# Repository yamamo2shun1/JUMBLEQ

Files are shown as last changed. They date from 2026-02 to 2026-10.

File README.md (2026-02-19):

# JUMBLEQ
“JUMBLEQ” is short for “jumbled equipment”

## Audio Spec.
- Analog: 4in/4out
- USB: 4in/4out(USB Audio Class 2.0) and MIDI in/out
- Format: 24bit, 48kHz/96kHz

## Electronic Spec.
- MCU: [STM32H7S3Z8](https://www.st.com/en/microcontrollers-microprocessors/stm32h7s3z8.html)
- DSP: [ADAU1466](https://www.analog.com/jp/products/adau1466.html)
- CODEC: [AK4619](https://www.akm.com/jp/ja/products/audio/audio-codec/ak4619vn/)
- IO: [Gateron Low Profile Magnet Jade Pro](https://www.gateron.com/products/gateron-full-pom-low-profile-magnetic-jade-pro-switch-set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) x6 and Pot x8

## for Windows User
I’m developing JUMBLEQ as a solo project. I can’t realistically develop both an ASIO driver and the necessary firmware support on my own. If you’re using this device on Windows, please use [ASIO4ALL](https://asio4all.org/)—even if you’d prefer a dedicated ASIO driver.

## Firmware Update
JUMBLEQ uses a UF2 bootloader.
When you connect the USB cable while holding down SW3, it is recognized as a USB flash drive, so you can update the firmware simply by copying app.uf2—created using the procedure below—to the drive.
```
> arm-none-eabi-objcopy -O binary JUMBLEQ_Appli.elf app.bin
> python uf2conv.py -c -b 0x90010000 -f STM32H7RS -o app.uf2 app.bin
```

## Block Diagram
JUMBLEQ_diagram

## Pinout (main board rev.C)
JUMBLEQ_main_pinout_revC

## Modules
- Original  
[AK4619 Audio Module](https://github.com/YamamotoWorksDev/AK4619_Module)  
Magnetic Switch & POT Module

- Third party  
[0.96インチ 128×64ドット有機ELディスプレイ(OLED) 白色](https://akizukidenshi.com/catalog/g/g112031/)  
[SparkFun Qwiic OLED Display (0.91 in., 128x32)](https://www.sparkfun.com/sparkfun-qwiic-oled-display-0-91-in-128x32-lcd-24606.html)  
[SparkFun Qwiic EEPROM Breakout - 512Kbit](https://www.sparkfun.com/sparkfun-qwiic-eeprom-breakout-512kbit.html)

## Byte Options

XSPI1_HSLV
DTCM_AXI_SHARE

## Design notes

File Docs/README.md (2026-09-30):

# JUMBLEQ Documentation

This directory contains user guides, technical reference material, and development notes for JUMBLEQ.

## User Guide

- [Operation Guide](./user-guide/operation-guide.md) — controls, signal routing, and device operation
- [Firmware update](./user-guide/firmware-update.md) — update JUMBLEQ using the built-in UF2 bootloader
- [JUMBLEQ Configurator](./user-guide/configurator.md) — change device settings from the Web app or alternative Max versions
- [Notes for Windows users](./user-guide/windows.md) — low-latency audio driver options

## Technical Reference

- [Audio specifications](./reference/audio-spec.md)
- [Hardware](./reference/hardware.md) — main components and PCB modules
- [Signal flow](./reference/signal-flow.md) — hardware block diagram and audio routing
- [MIDI](./reference/midi/README.md) — receive and transmit specifications
- [Naming conventions](./reference/naming-conventions.md) — self-written Core code identifiers

## Development

- [Development environment](./development/environment.md)
- [ST-LINK debug configuration](../STM32CubeIDE/docs/Debug_Configuration-STLINK.md)
- [J-Link debug configuration](../STM32CubeIDE/docs/Debug_Configuration-JLINK.md)
- [Build and UF2 generation](./development/build-and-uf2.md)
- [STM32H7S3 errata](./development/errata.md)
- [STM32CubeIDE project overview](../STM32CubeIDE/README.md)

## Project History

See the [Gallery](../Gallery/) for photographs and notes from each prototype stage.

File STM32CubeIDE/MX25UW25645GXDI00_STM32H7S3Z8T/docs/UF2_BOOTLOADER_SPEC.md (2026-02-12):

# UF2ブートローダ 仕様整理（MX25UW25645GXDI00_STM32H7S3Z8T）

更新日: 2026-02-12

## 前提
- 対象プロジェクト: MX25UW25645GXDI00_STM32H7S3Z8T
- 現状は外部フラッシュ（XIP）アプリを起動するシンプル構成
- 追加するのは UF2 ブートローダ（USB MSC 経由）

## 決定済み要件
- ブートモード入口: SW2 を押しながら電源 ON（USB 接続）
- USB: HS（High Speed）使用
- 検証: CRC32 のみ
- アプリ配置: 外部フラッシュ上の固定オフセット
- ボリューム名: UF2BOOT
- USB VID/PID: 0x31BF / 0x0100

## 目的
- USB MSC として UF2 を受け取り、外部フラッシュのアプリ領域へ書き込み
- CRC32 検証後に XIP でアプリ起動

## 起動フロー（方針）
1. 低レベル初期化（クロック / MPU / キャッシュ）
2. XSPI + ExtMem Manager 初期化
3. ブートモード判定
   - SW2 押下かつ USB 接続なら UF2 モード
   - それ以外はアプリ起動
4. UF2 モード
   - USB MSC デバイス起動
   - UF2 ブロック受信 -> 外部フラッシュ書き込み
   - CRC32 検証 OK ならメタデータ更新
5. 通常モード
   - XIP アプリへジャンプ

## メモリマップ（方針）
- 内蔵フラッシュ
  - ブートローダ格納
- 外部フラッシュ（32MB = 0x0200_0000）
  - META 領域: 0x9000_0000 - 0x9000_FFFF (64KB)
  - APP 領域: 0x9001_0000 - 0x9040_FFFF (4MB)
  - 予備:     0x9041_0000 - 0x91FF_FFFF (残り)

### 固定オフセット
- `APP_OFFSET = 0x0001_0000` (64KB)
- `APP_BASE   = 0x9000_0000 + APP_OFFSET = 0x9001_0000`
- `EXTMEM_XIP_IMAGE_OFFSET` は `APP_OFFSET` と同値にする
- `EXTMEM_HEADER_OFFSET` は 0

※ META 領域は最小 4KB でも良いが、消去セクタ境界に合わせ 64KB を確保する前提。

## 消去・書き込み戦略（推奨）
- デバイスは 4KB セクタ消去と 64KB ブロック消去をサポート
- APP 領域は 64KB ブロック単位で消去（更新時間短縮のため）
- META のような小領域は 4KB セクタ消去を許可
- UF2 受信時は、書き込み対象アドレス範囲に対応する 64KB ブロックのみ事前消去

## UF2 処理方針
- USB MSC で 512B UF2 ブロックを受信
- `targetAddr` を外部フラッシュ APP 領域にマップ
- ブロック毎に書き込み
- 受信完了後、CRC32 を算出
- CRC32 OK -> META 更新

## UF2 MSC 仮想ディスク構成（提案）
- 目的: 4MB アプリの UF2 ファイル（サイズ約 8MB）を無理なく転送できる容量を確保
- ディスクサイズ: 16MB（16384KB）
- セクタサイズ: 512B
- クラスタサイズ: 1 セクタ
- FAT: FAT16
- ルートエントリ数: 64
- ボリュームラベル: `UF2BOOT`

### 生成するファイル（読み取り専用）
- `INFO_UF2.TXT`
  - ボード名/ビルド情報/対応範囲など
- `INDEX.HTM`
  - 製品ページや手順案内への誘導（必要なら）
- `CURRENT.UF2`（任意）
  - 現在のアプリを吸い出す用途（不要なら省略）

### 書き込み受理ルール
- UF2 ブロックのみ受理（UF2 マジック一致）
- `targetAddr` が `APP_BASE .. APP_BASE + APP_SIZE - 1` にあるものだけ書き込み
- 範囲外は無視（ディスクの通常書き込みは無視）
- 初回書き込み時に対象 64KB ブロックだけ消去
- `numBlocks` と `blockNo` を用いて受信完了を判断し CRC32 検証

## 運用手順（UF2 生成と書き込み）
### 前提
- アプリのリンクアドレスは `0x90010000`（APP_BASE）
- UF2 変換は `uf2conv.py` を使用
- `uf2families.json` は `uf2conv.py` と同じフォルダに置く
- family ID: `STM32H7RS = 0x6db66083`

### 1. ELF -> BIN 変換
```
arm-none-eabi-objcopy -O binary app.elf app.bin
```

### 2. BIN -> UF2 変換
```
python uf2conv.py -c -b 0x90010000 -f STM32H7RS -o app.uf2 app.bin
```

### 3. 書き込み
- SW2 押下で電源 ON（USB 接続）
- PC に `UF2BOOT` がマウントされる
- `app.uf2` を `UF2BOOT` にドラッグ＆ドロップ
- 書き込み完了後、自動でアプリへジャンプ

## CRC32 メタデータ仕様（提案）

### 位置
- META ベース: `0x9000_0000`
- 先頭 256B をメタデータ領域として使用

### 形式（リトルエンディアン）
```
typedef struct {
  uint32_t magic;       // 0x4D544131 ('MTA1')
  uint16_t version;     // 0x0001
  uint16_t header_size; // sizeof(MetaHeader) = 64
  uint32_t flags;       // bit0: valid
  uint32_t app_base;    // 0x90010000
  uint32_t app_size;    // max 0x00400000
  uint32_t app_crc32;   // CRC32(アプリ全体)
  uint32_t build_id;    // 任意 (ビルド番号 or Git short hash)
  uint32_t image_size;  // 実際に書き込んだサイズ
  uint32_t reserved[6]; // 0
} MetaHeader;
```

### 更新タイミング
- UF2 受信完了後に CRC32 を算出
- CRC32 が一致した場合のみ `flags.valid = 1` として META を更新
- 更新時は 4KB セクタ消去 -> 先頭 256B 書き込み

### 検証タイミング
- 起動時に `magic/version/header_size` を確認
- `flags.valid == 1` かつ `app_size` が上限内なら CRC32 検証
- 一致すれば XIP 起動、失敗なら UF2 モードへ

## LED 表示パターン（提案）
- 通常起動（XIPアプリへジャンプ）: LED0 1秒点灯 -> 消灯
- UF2待機（SW2押下で起動した更新モード）: LED0 ゆっくり点滅（1Hz）
- UF2書き込み中: LED1 速い点滅（4Hz）
- CRC32検証中: LED2 ブリージング（0.5Hz）
- 検証OK / 起動準備: LED0+LED1+LED2 を200ms同時点灯 -> 消灯
- 検証NG / エラー: LED2 2連点滅（100ms×2）を1秒周期で繰り返し
- USB未接続でSW2押下（無効）: LED1 3回短点滅

## XIP 起動方針
- `VTOR = APP_BASE`
- `MSP = *(uint32_t*)APP_BASE`
- `PC  = *(uint32_t*)(APP_BASE + 4)`
- キャッシュ clean/invalidate を実施してからジャンプ

## 現行 Boot 実装の確認（2026-02-12）
- `BOOT_Application()` は `stm32_boot_xip.c` に実装
- `MapMemory()` で `extmem_list_config` の全メモリを `EXTMEM_MemoryMappedMode()` へ
- `EXTMEM_MEMORY_BOOTXIP` が非対応なら `BOOT_ERROR_INCOMPATIBLEMEMORY`
- `JumpToApplication()` は以下の順で実行
  - `EXTMEM_GetMapAddress(EXTMEM_MEMORY_BOOTXIP, &Application_vector)`
  - `EXTMEM_XIP_IMAGE_OFFSET` と `EXTMEM_HEADER_OFFSET` を加算（現状は未定義のため両方 0）
  - SysTick / I-Cache / D-Cache を停止
  - `VTOR` 設定 -> `MSP` 設定 -> `PC` にジャンプ
- `Boot/Core/Src/main.c` では以下の順に初期化
  - `MX_XSPI1_Init()`
  - `MX_EXTMEM_MANAGER_Init()`
  - `BOOT_Application()`
- MPU では `0x90000000` を 32MB サイズで実行可・キャッシュ可として設定
- リンカは内蔵フラッシュ `0x08000000` から 64KB をブートローダ領域として使用
- `extmem_list_config` は NOR SFDP + XSPI1 + 8lines で初期化

## 次のアクション候補（残り）
1. 実装作業（ブートモード判定、USB MSC、UF2書き込み、META更新、LED制御）に着手

## 実装状況（2026-02-12）
- ブートモード判定、UF2解析、外部フラッシュ書き込み、META更新、LED制御の骨格を実装
- USB MSC は TinyUSB で動作（HS）
- MSC は最小FAT16（16MB）を返す読み取り専用ディスクとして実装
- UF2 書き込み後に CRC32 検証 -> 自動ジャンプまで動作確認済み

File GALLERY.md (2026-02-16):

## Gallery
DSCF6374
DSCF6384
DSCF6378

## Prototype 2
DSCF6407
DSCF6405
DSCF6411
DSCF6414
DSCF6415
DSCF6416

## Prototype 1
DSCF6165-2
DSCF6172-2
DSCF6176-2

## Main board
OTO_overall
OTO_top

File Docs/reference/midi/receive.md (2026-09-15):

# MIDI Receive Specification

This document describes the MIDI receive specification based on the `JUMBLEQ/Appli/Core` implementation as of September 2026.

## 1. Overview

- Incoming MIDI messages are processed over USB MIDI.
- Incoming messages used to change UI settings are accepted only on **MIDI Ch. 15** (1-based channel numbering).

## 2. Program Change (Host -> Device)

### 2.1 Acceptance Conditions

- Program Change messages are accepted only on MIDI Ch. 15.
- Program Change messages on all other channels are ignored.

### 2.2 Program Change Map

| PC Number | Function |
|---:|---|
| 0/1 | Set the Ch. 1 input type (Line / Phono). |
| 2/3 | Set the Ch. 2 input type (Line / Phono). |
| 4/5/6/7 | Assign an input source (Ch. 1 / Ch. 2 / USB[1/2] / USB[3/4]) to Channel Fader A. |
| 8/9/10/11 | Assign an input source (Ch. 1 / Ch. 2 / USB[1/2] / USB[3/4]) to Channel Fader B. |
| 12/13/14/15 | Assign an input source (Ch. 1 / Ch. 2 / USB[1/2] / USB[3/4]) to Post Fader. |
| 16/17/18 | Set the Ch. 1 input mode (Off / DVS / SYNTH). |
| 19/20/21 | Set the Ch. 2 input mode (Off / DVS / SYNTH). |
| 22/23/24 | Select the Return source (USB[1/2] / USB[3/4] / None). |
| 25/26/27/28 | Select the headphone output source (FADER_A / FADER_B / THRU / MASTER). |
| 29/30 | Assign magnetic switch 2 to the auxiliary fade-down function for Channel Fader A or B. |
| 31/32 | Assign magnetic switch 3 to the auxiliary fade-down function for Channel Fader A or B. |
| 33/34 | Set the Channel Fader A direction (Normal / Reverse). |
| 35/36 | Set the Channel Fader B direction (Normal / Reverse). |
| 37/38/39 | Select the global SYNTH Ratio Set (Octave / Harmonic / Chord). |
| 40/41/42/43 | Select the global SYNTH Warp Algorithm (Clean / Crossfold / Ring Mod / Comparator). |
| 120/121 | Disable or enable Channel Fader curve edit mode. |
| 122/123 | Select the output mode (CC / Note) for magnetic controls and channel fader sensors. |
| 124 | Arm the 10-second physical confirmation window for UF2 bootloader mode. |
| 125 | Cancel the UF2 bootloader confirmation window. |
| 126 | Transmit a dump of the parameters currently configured on the device. |
| 127 | Save the current settings to EEPROM. |

Notes:

- `PC24` selects `None`, which disables the Return signal path.
- Auxiliary fade-down assignments for magnetic switches 2 and 3 take effect immediately when the Program Change message is received.
- The default assignments are Channel Fader A for magnetic switch 2 and Channel Fader B for magnetic switch 3.
- Direction can be configured independently for Channel Faders A and B and takes effect immediately. The default is Normal for both faders.
- Reverse inverts the final fader response for Fade Up and all Fade Down controls assigned to that fader, including auxiliary Fade Down controls. It does not change the live MIDI values transmitted by the individual magnetic sensors.
- Ratio Set and Warp Algorithm are shared by Input Ch. 1 and Input Ch. 2. Changes take effect immediately for both oscillator instances.
- Warp Amount is controlled independently by the existing CC.5 potentiometer. Selecting Clean bypasses warping, so CC.5 has no audible effect until another Warp Algorithm is selected.
- `PC127` saves the complete device configuration listed in Section 6 to EEPROM, including the SYNTH Ratio Set and Warp Algorithm.
- `PC126` transmits the **current operating state (parameters eligible for saving)** rather than reading and transmitting the EEPROM contents.
- `PC124` never resets the device by itself. After it is received, SW3 must be observed released and then held continuously for 2 seconds before the device resets into UF2 mode.
- The PC124 confirmation window is cancelled by `PC125`, a 10-second timeout, or USB disconnection. Repeated PC124 messages do not extend an active window.
- PC124 and PC125 are transient commands and are not included in configuration dumps or EEPROM storage.

## 3. Safe UF2 Bootloader Transition

The Configurator can request a safe transition to the UF2 bootloader as follows:

1. Send PC124 on Ch. 15.
2. Wait for the main OLED to request physical confirmation.
3. Release SW3, then hold it continuously for 2 seconds.
4. Keep SW3 held while the device resets and the UF2 mass-storage volume appears.

The main OLED shows the remaining time, the required switch action, and cancellation or timeout status. PC124 received while a confirmation window is already active is ignored and does not restart or extend the timer.

After the 2-second hold is accepted, the firmware clears both OLED displays and then resets while SW3 remains pressed. The existing bootloader selects UF2 mode using its normal startup switch check; no persistent boot request is stored.

## 4. Control Change (Host -> Device)

### 4.1 Acceptance Conditions

Control Change messages are accepted only when all of the following conditions are met:

- Channel Fader curve edit mode is enabled.
- The MIDI channel is Ch. 15.
- The CC number is supported (`20`, `21`, or `22`).

### 4.2 Control Change Map

| CC Number | Parameter | CC Value |
|---:|---|---|
| 20 | `XFADE_CURVE_A` | 0 to 127 |
| 21 | `XFADE_CURVE_B` | 0 to 127 |
| 22 | `DVS_FADER_DELAY_MS` | 0 to 120 ms; values 121 to 127 are clamped to 120 ms |

Curve response:

- `0` selects the strongest late-rise curve; the level changes mainly near the end of the key travel.
- `64` selects an exactly linear response across the full key travel.
- `127` selects the strongest early-rise curve; the level changes sharply near the start of the key travel.
- The late- and early-rise families use point-reflected exponential curves.
- The default value is `64` for both Channel Faders A and B.
- The DVS fader delay defaults to 50 ms and is shared by both input channels.

## 5. `curve_edit_mode` (Channel Fader Curve Edit Mode) Behavior

- Use Program Change messages to enable or disable the mode (`PC121` ON / `PC120` OFF).
- While enabled, the main OLED shows the current curve CC values for Channel Faders A and B together with a graphical preview of each curve. The first line shows `FADER DLY: nms` when either DVS channel is enabled and `FADER DLY: ---` when both are disabled.
- While disabled, the main OLED uses its normal display and shows the gain values for each input and output channel.
- There is no automatic timeout.

## 6. EEPROM Storage and Startup Restore

- Save trigger: `PC127` on Ch. 15
- Saved parameters:
  - CH1/CH2 input types
  - Channel Fader A/B and Post Fader assignments
  - CH1/CH2 input modes (Off / DVS / SYNTH)
  - DVS magnetic-switch fader delay
  - Return source assignment
  - Headphone output source
  - Magnetic output mode (CC / Note)
  - Auxiliary fade-down assignments for magnetic switches 2 and 3
  - Direction settings (Normal / Reverse) for Channel Faders A/B
  - Curve settings for Channel Faders A/B
  - SYNTH Ratio Set and Warp Algorithm shared by both input channels
- EEPROM record version: `0x0009`
  - `0x0008` records are migrated with Ratio Set = Octave and Warp Algorithm = Crossfold.
  - `0x0007` records are loaded with a 50 ms DVS fader delay, their DVS booleans are converted to Off/DVS input modes, and the same SYNTH defaults are applied.

## 7. Implementation Notes

- Channel values in the implementation are zero-based (for example, `14` = MIDI Ch. 15).
- The Ch. 15 restrictions for incoming Program Change and Control Change messages are checked in their respective dispatch functions.
- Internally, `CC64` maps to zero exponential curvature. Values below it produce negative (late-rise) curvature, and values above it produce positive (early-rise) curvature. The absolute bipolar curve amount is cubed before it scales the exponent, providing finer adjustment around the linear midpoint while preserving the endpoint curves. The maximum curvature is calibrated so the `CC127` response reaches 90% output at 2% key travel. EEPROM retains the legacy normalized-width representation for backward compatibility; that stored value is converted back to its CC value before the exponential curve is evaluated.

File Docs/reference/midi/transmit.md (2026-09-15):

# MIDI Transmit Specification

This document describes the MIDI transmit specification based on the `JUMBLEQ/Appli/Core` implementation as of September 2026.

## 1. Overview

- Outgoing MIDI messages are sent to the host over USB MIDI.
- Live control output is sent on MIDI Ch. 1.
- Configuration dump responses are sent on MIDI Ch. 15.

## 2. Live Control Output (Device -> Host)

The device transmits the following messages on MIDI Ch. 1. In the implementation, channel value `0` corresponds to MIDI Ch. 1.

| Control | CC Mode | Note Mode | Description |
|---|---|---|---|
| MIDI-assigned potentiometers | CC `0..4` | — | Sends the current knob value. |
| Magnetic controls 0..3 | CC `12..15` | Notes `68..71` | Output mode is selected using `PC122` or `PC123`. |
| Magnetic channel fader sensors 0..5 | CC `20..25` | Notes `60..65` | Output mode is selected using `PC122` or `PC123`. |

In CC mode, magnetic channel fader updates are sent only when the normalized raw value changes by more than `0.01`. This reduces MIDI traffic and jitter.

In Note mode, magnetic controls and channel fader sensors send Note On/Off messages. The peak sensor value measured during the initial 12 ms window is converted to Note On velocity.

CC20 through CC22 have different roles depending on the MIDI channel: on Ch. 1 they carry live values from magnetic channel fader sensors 0 through 2. In a Ch. 15 configuration dump, CC20 and CC21 carry curve settings for Channel Faders A and B, while CC22 carries the DVS fader delay.

## 3. Implementation Notes

- Channel values in the implementation are zero-based (for example, `0` = MIDI Ch. 1).
- `PC122` selects CC output for magnetic controls and channel fader sensors.
- `PC123` selects Note output for magnetic controls and channel fader sensors.

## 4. Configuration Dump Response (When PC126 Is Received)

When the device receives `PC126` on Ch. 15 from the host, it sends the current values of all parameters eligible for saving back to the host.

- Transmit channel: **MIDI Ch. 15** (implementation value `14`)
- Message types: Program Change and Control Change

### 4.1 Program Change (Device -> Host, Ch. 15)

| PC Value | Meaning |
|---:|---|
| 0/1 | Ch. 1 input type (Line / Phono) |
| 2/3 | Ch. 2 input type (Line / Phono) |
| 4/5/6/7 | Channel Fader A source (Ch. 1 / Ch. 2 / USB[1/2] / USB[3/4]) |
| 8/9/10/11 | Channel Fader B source (Ch. 1 / Ch. 2 / USB[1/2] / USB[3/4]) |
| 12/13/14/15 | Post Fader source (Ch. 1 / Ch. 2 / USB[1/2] / USB[3/4]) |
| 16/17/18 | Ch. 1 input mode (Off / DVS / SYNTH) |
| 19/20/21 | Ch. 2 input mode (Off / DVS / SYNTH) |
| 22/23/24 | Return source (USB[1/2] / USB[3/4] / None) |
| 25/26/27/28 | Headphone output source (FADER_A / FADER_B / THRU / MASTER) |
| 29/30 | Auxiliary fade-down assignment for magnetic switch 2 (Channel Fader A/B) |
| 31/32 | Auxiliary fade-down assignment for magnetic switch 3 (Channel Fader A/B) |
| 33/34 | Channel Fader A direction (Normal / Reverse) |
| 35/36 | Channel Fader B direction (Normal / Reverse) |
| 37/38/39 | Global SYNTH Ratio Set (Octave / Harmonic / Chord) |
| 40/41/42/43 | Global SYNTH Warp Algorithm (Clean / Crossfold / Ring Mod / Comparator) |
| 122/123 | Output mode for magnetic controls and channel fader sensors (CC / Note) |

The dump contains exactly one value for each setting group, including one Ratio Set value and one Warp Algorithm value. Ratio Set and Warp Algorithm are global settings shared by both SYNTH channels.

### 4.2 Control Change (Device -> Host, Ch. 15)

| CC Number | Meaning |
|---:|---|
| 20 | `XFADE_CURVE_A` (`0` = strongest late rise, `64` = linear, `127` = strongest early rise) |
| 21 | `XFADE_CURVE_B` (`0` = strongest late rise, `64` = linear, `127` = strongest early rise) |
| 22 | `DVS_FADER_DELAY_MS` (`0..120` ms) |

The curve values use the same scale as incoming curve-edit Control Change messages. The DVS fader delay value is transmitted directly in milliseconds. This allows the host to restore the current settings without conversion.

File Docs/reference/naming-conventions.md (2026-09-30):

# JUMBLEQ 自作コード命名規則

この文書は `STM32CubeIDE/JUMBLEQ/Appli/Core` の自作コードに適用する命名規則を定義する。
外部・生成コードの識別子には適用しない。

## 対象外

- STM32CubeMX生成コードの識別子（`MX_*`、`HAL_*`、`Start*Task`、`*TaskHandle`、`main.c` の生成部など）
- HAL / CMSIS / FreeRTOS / TinyUSB / SEGGER / SigmaStudio+ / TCPP0203 / stm32-ssd1306 が所有する識別子
- DMA/リンカ契約シンボル（`adc_val`、`sai_tx_dma_buf`、`sai_rx_dma_buf`、`Node_*`、`List_*`）
- FreeRTOS契約シンボル（`ucHeap`）

## 関数

- 公開API: `<module>_<verb>_<object>` の lower_snake_case。
- private（static）関数: lower_snake_case。所有モジュールの接頭辞を付けることを推奨する。
- 識別子内で大文字小文字を混ぜない（`typeA` ではなく `type_a`）。

## 型

型名は `<component>_<name>_t` の lower_snake_caseとし、匿名 struct / union / enum の typedef で定義する。
componentは次の優先順で決める。

1. 永続診断型は、対応する診断グローバル名から `g_` を除いた名前をcomponentとする。
   - 例: `g_audio_tx_diagnostics` → `audio_tx_diagnostics_t`
   - 例: `g_audio_usb_feature_diagnostics` → `audio_usb_feature_diagnostics_t`
   - 例: `g_sigma_spi_diagnostics` → `sigma_spi_diagnostics_t`
2. それ以外は所有モジュールの接頭辞をcomponentとする。

| 所有モジュール（定義ファイル） | component |
| --- | --- |
| adau1466.h / adau1466.c | `adau1466_` |
| eeprom.h / eeprom.c | `eeprom_` |
| eeprom_config_internal.h / eeprom_config.c | `eeprom_config_` |
| timecode_oscillator.h / timecode_oscillator.c | `timecode_oscillator_` |
| timecode_synth.h / timecode_synth.c | `timecode_synth_` |
| audio_control_internal.h / audio_control.c | `audio_control_` |
| audio_transport_internal.h / audio_transport.c | `audio_transport_` |
| audio_usb_control_internal.h / audio_usb_control.c | `audio_usb_control_` |
| ui_control.h / ui_control.c | `ui_control_` |
| ui_persist_internal.h | `ui_persist_` |
| ui_midi_control_internal.h / ui_midi_control.c | `ui_midi_control_` |
| ui_uf2_control_internal.h / ui_uf2_control.c | `ui_uf2_control_` |
| ui_pot_control_internal.h / ui_pot_control.c | `ui_pot_control_` |
| ui_routing_control_internal.h / ui_routing_control.c | `ui_routing_`（関数接頭辞が `ui_routing_*` のため） |
| ui_ch_fader_internal.h / ui_ch_fader.c | `ui_ch_fader_` |
| led_control.c | `led_` |

- 所有が定義ファイルと異なる型は所有をコメント等で明記する。
  例: `audio_transport_failure_t` は audio_transport 所有（include循環を避けるため宣言のみ `audio_diagnostics_internal.h` に置く）。

## 変数・定数

- ファイルスコープオブジェクト: `static` + `s_` + lower_snake_case。const有無を問わない。
- 複数翻訳単位で共有するグローバル: `g_` + lower_snake_case。型名と一致させる必要はない。
- ブロックスコープstatic: 宣言位置で局所性が明確なため `s_` は付けず、lower_snake_caseとする。
- マクロ・enum値: UPPER_SNAKE_CASE。

## 単位

物理量を表す名前に単位接尾辞を付ける。無次元（0..1の比率など）には付けない。

`_ms`、`_us`、`_hz`、`_db`、`_bytes`、`_words`、`_frames`、`_samples`、`_count`、`_tick`

## 略語

次の略語を許容する。

`src`、`db`、`cfg`、`ptr`、`buf`、`len`、`idx`、`num`、`min`、`max`、`avg`、`prev`、`init`

- 同一概念で長短を混在させない（例: `audio_diag_` と `audio_diagnostics_` を混ぜない）。
- モジュールAPIの接頭辞は、そのモジュールの公開・内部ヘッダーの関数接頭辞と一致させる。

## 診断変数の例外

デバッガから参照する診断変数は、次の例外を認める。

- `dbg_` + lower_snake_case（例: `dbg_tx_used_min`、`dbg_usb_isr_count`）
- `.noinit` に置くFault記録（`g_hardFaultInfo` / `HardFaultInfo_t`）は名称・可視性とも変更しない。

診断変数の可視性（static / 非static）を変更する場合は、デバッガのWatch式や手動デバッグでの用途を確認し、
参照名の変更を明示してから行う。

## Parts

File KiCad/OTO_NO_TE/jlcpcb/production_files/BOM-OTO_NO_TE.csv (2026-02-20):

Comment | Designator | Footprint | LCSC | Quantity
100nF | C1 | C_0603_1608Metric_Pad1.08x0.95mm_HandSolder | C161117 | 1
10k | RV1,RV10,RV11,RV12,RV2,RV3,RV4,RV5,RV6,RV7,RV8,RV9 | RK09K1130A5R | C209779 | 12
DRV5056A3QDBZR | U1,U10,U11,U2,U3,U4,U5,U6,U7,U9 | SOT-23 | C2866615 | 10
CD74HC4067M | U8 | SOIC-24W_7.5x15.4mm_P1.27mm | C496123 | 1
10nF | C2,C25,C27,C29,C3,C31,C4,C5,C6,C7 | C_0402_1005Metric | C77019 | 10
100nF | C14,C15,C16,C17,C18,C19,C20,C21,C22,C23 | C_0402_1005Metric | C77020 | 10
Conn_01x06 | J1 | PinHeader_1x06_P2.54mm_Vertical |  | 1
~ | R4 | R_0603_1608Metric_Pad0.98x0.95mm_HandSolder |  | 1
~ | C13 | C_0603_1608Metric_Pad1.08x0.95mm_HandSolder |  | 1
~ | R6 | R_0603_1608Metric_Pad0.98x0.95mm_HandSolder |  | 1
~ | R5 | R_0603_1608Metric_Pad0.98x0.95mm_HandSolder |  | 1
~ | R1 | R_0603_1608Metric_Pad0.98x0.95mm_HandSolder |  | 1
~ | C9 | C_0603_1608Metric_Pad1.08x0.95mm_HandSolder |  | 1
~ | C10 | C_0603_1608Metric_Pad1.08x0.95mm_HandSolder |  | 1
~ | C11 | C_0603_1608Metric_Pad1.08x0.95mm_HandSolder |  | 1
~ | R3 | R_0603_1608Metric_Pad0.98x0.95mm_HandSolder |  | 1
~ | C12 | C_0603_1608Metric_Pad1.08x0.95mm_HandSolder |  | 1
~ | R2 | R_0603_1608Metric_Pad0.98x0.95mm_HandSolder |  | 1
~ | C8 | C_0603_1608Metric_Pad1.08x0.95mm_HandSolder |  | 1
~ | ICLED7 | 1312020030000 |  | 1
~ | ICLED10 | 1312020030000 |  | 1
~ | ICLED8 | 1312020030000 |  | 1
~ | ICLED5 | 1312020030000 |  | 1
~ | ICLED4 | 1312020030000 |  | 1
~ | ICLED2 | 1312020030000 |  | 1
~ | ICLED1 | 1312020030000 |  | 1
~ | ICLED3 | 1312020030000 |  | 1
~ | ICLED6 | 1312020030000 |  | 1
~ | ICLED9 | 1312020030000 |  | 1
~ | R10 | R_0603_1608Metric_Pad0.98x0.95mm_HandSolder |  | 1
~ | R9 | R_0603_1608Metric_Pad0.98x0.95mm_HandSolder |  | 1
~ | C30 | C_0603_1608Metric_Pad1.08x0.95mm_HandSolder |  | 1
~ | C28 | C_0603_1608Metric_Pad1.08x0.95mm_HandSolder |  | 1
Conn_01x06 | J3 | PinHeader_1x06_P2.54mm_Vertical |  | 1
Conn_01x06 | J2 | PinHeader_1x06_P2.54mm_Vertical |  | 1
~ | R7 | R_0603_1608Metric_Pad0.98x0.95mm_HandSolder |  | 1
~ | C26 | C_0603_1608Metric_Pad1.08x0.95mm_HandSolder |  | 1
~ | R8 | R_0603_1608Metric_Pad0.98x0.95mm_HandSolder |  | 1
~ | C24 | C_0603_1608Metric_Pad1.08x0.95mm_HandSolder |  | 1

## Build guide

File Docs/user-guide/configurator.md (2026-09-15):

# JUMBLEQ Configurator

JUMBLEQ Configurator changes device settings by sending MIDI messages to JUMBLEQ.

## Web App (Recommended)

The browser-based [JUMBLEQ Configurator](https://configurator.jumbleq.io/) is the primary version and receives maintenance priority. It runs without installing a dedicated application; use a browser with Web MIDI support and connect JUMBLEQ to the computer over USB.

[Open JUMBLEQ Configurator](https://configurator.jumbleq.io/)

### Getting Started

1. Connect JUMBLEQ to the computer over USB and power it on.
2. Open the Web app and allow MIDI access when prompted by the browser.
3. Confirm that the connection status shows **JUMBLEQ connected** and that the device settings are synchronized.

The Web app provides controls for input and channel-fader routing, channel-fader response curves, DVS, global SYNTH Ratio Set and Warp Algorithm selection, monitor and Return routing, magnetic-switch behavior, and device settings. It also supports reading the current settings from JUMBLEQ and importing or exporting presets.

### Using the Web App on iPad

Safari does not provide Web MIDI. To connect JUMBLEQ from an iPad:

1. Install [MIDIWeb Browser](https://apps.apple.com/jp/app/midiweb-browser/id6757226617?l=en-US) from the App Store.
2. Connect JUMBLEQ to the iPad over USB and power it on.
3. Open [configurator.jumbleq.io](https://configurator.jumbleq.io/) inside MIDIWeb Browser.
4. Select **Connect device**, allow MIDI access, and wait for the settings to synchronize.

Connection and MIDI communication have been verified with MIDIWeb Browser on iPadOS 26.5.

JUMBLEQ Configurator Web app showing routing and channel-fader settings
<img width="480"" alt="UMBLEQ Configurator Web app showing controls and device settings" src="https://github.com/user-attachments/assets/36ef499a-27e5-489c-96c2-58ebba73b6ec" />

## Alternative Max Versions

The Max Standalone and Max for Live versions remain in the repository for existing workflows, but they have a lower maintenance priority than the Web app. Their source files and packaged versions are available in the [`Max` directory](../../Max/). The source patches expose Off, DVS, and SYNTH input-mode choices for both input channels.

### Max Standalone

The Max source patch can be opened with [Max 9](https://cycling74.com/products/max-9). Packaged archives for Windows and macOS are also retained in the `Max` directory.

JUMBLEQ Configurator for Max

### Max for Live

The [Max for Live device](../../Max/JUMBLEQ_Configurator.amxd) allows JUMBLEQ settings to be changed directly from Ableton Live.

JUMBLEQ Configurator for Max for Live

For the MIDI messages used by the configurator, see the [MIDI reference](../reference/midi/README.md).

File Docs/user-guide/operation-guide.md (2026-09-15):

# Operation Guide

This guide explains JUMBLEQ's physical controls, audio routing, USB signal routing, input operating modes, and OLED indications.

## Signal Routing Overview

Audio sources are assigned to Channel Faders A and B using [JUMBLEQ Configurator](./configurator.md). In standard operation, the Channel Fader A signal is sent to USB 1/2 and the Channel Fader B signal is sent to USB 3/4. Either USB pair can be selected as a Return source and mixed with its corresponding channel-fader signal.

See the [Signal Flow reference](../reference/signal-flow.md) for the detailed audio-routing diagram.

## Input Operating Modes and USB Signal Routing

Input Ch. 1 and Input Ch. 2 can each be set independently to Off, DVS, or SYNTH using a compatible configurator. Off selects standard mixer routing, while DVS selects the existing USB DVS send/return path. SYNTH analyzes the connected timecode-vinyl signal in the STM32 and returns the generated oscillator audio to the pre-fader path without sending that channel through USB.

The Configurator also selects a Ratio Set (Octave, Harmonic, or Chord) and Warp Algorithm (Clean, Crossfold, Ring Mod, or Comparator). These two selections are global and therefore apply to both SYNTH channels. They take effect immediately and are stored by Save to device. Clean bypasses the warp stage; in that algorithm, the CC.5 Warp Amount knob has no audible effect.

DVS can be enabled independently for Input Ch. 1 and Input Ch. 2 using [JUMBLEQ Configurator](./configurator.md). The DVS state changes the USB Send source as follows:

| DVS state | Send source | Destination |
|---|---|---|
| Disabled | Channel Fader A (post-fader) | USB 1/2 |
| Disabled | Channel Fader B (post-fader) | USB 3/4 |
| Input Ch. 1 enabled | Input Ch. 1 (pre-fader) | USB 1/2 |
| Input Ch. 2 enabled | Input Ch. 2 (pre-fader) | USB 3/4 |

### When DVS Is Disabled

When DVS is disabled for a USB pair, its corresponding channel-fader signal is sent to the connected USB host as shown in the table above. The Return source can be set to any USB pair whose corresponding DVS setting is disabled, or to None:

| Return setting | Wet signal | Dry signal |
|---|---|---|
| USB 1/2 | USB 1/2 | Channel Fader A (post-fader) |
| USB 3/4 | USB 3/4 | Channel Fader B (post-fader) |
| None | Muted | Channel Faders A and B remain fully dry |

The Dry/Wet knob crossfades the selected Wet signal against its corresponding Dry signal. At 0% the selected path is fully dry; at 100% it is fully wet. The Return knob adjusts the level of the selected Wet signal.

When Return is set to None, Dry is fixed at 100% and Wet at 0%. The Dry/Wet and Return knobs therefore have no effect.

### When DVS Is Enabled

The USB pair corresponding to the enabled DVS channel is used for the DVS send and return path instead of the standard channel-fader Send and selectable Return path. JUMBLEQ Configurator prevents that USB pair from being selected as the Return source.

The Dry/Wet and Return knobs do not control the DVS path. If the other USB pair is not reserved by DVS and is selected as the Return source, both knobs continue to control that Return path normally.

Magnetic-switch changes to a channel fader reach the DSP with a configurable control delay when the corresponding input's DVS setting is enabled. The delay is shared by both input channels, can be set from 0 to 120 ms, and defaults to 50 ms. Input Ch. 1 and USB 1/2 assignments follow Ch. 1 DVS; Input Ch. 2 and USB 3/4 assignments follow Ch. 2 DVS. This includes PC-return audio assigned directly from USB. The delay follows the input assignment of each fader, including when A and B are swapped. When the corresponding DVS setting is disabled, the fader responds without this additional delay. Magnetic-switch MIDI output retains its existing timing.

Successive fader changes are queued in order, so a brief cut is delayed together with its release. Actual timing also includes the UI task and DSP-write scheduling. Changing the assigned input, its DVS state, or the configured delay cancels pending changes and synchronizes the DSP to the current fader target. While curve edit mode is active, the main OLED shows `FADER DLY: nms` when either DVS channel is enabled and `FADER DLY: ---` when both are disabled.

## Knob Assignments

The following diagram shows the current knob assignments.



### Knob Functions

| Panel label | Range | Function |
|---|---:|---|
| CC.1 | 0–127 | Sends MIDI CC 0 on MIDI Ch. 1 and controls Root when either input is in SYNTH mode. |
| CC.2 | 0–127 | Sends MIDI CC 1 on MIDI Ch. 1 and controls Morph when either input is in SYNTH mode. |
| CC.3 | 0–127 | Sends MIDI CC 2 on MIDI Ch. 1 and controls Slope when either input is in SYNTH mode. |
| CC.4 | 0–127 | Sends MIDI CC 3 on MIDI Ch. 1 and controls Smooth/Fold when either input is in SYNTH mode. |
| CC.5 | 0–127 | Sends MIDI CC 4 on MIDI Ch. 1 and controls Warp Amount when either input is in SYNTH mode. |
| Input Ch. 1 | −80 to +10 dB | Adjusts the level of the analog Channel 1 input before it is routed through the mixer or to the DVS send path. |
| Input Ch. 2 | −80 to +10 dB | Adjusts the level of the analog Channel 2 input before it is routed through the mixer or to the DVS send path. |
| Output Ch. 1 | −80 to +10 dB | Adjusts the level of the analog Channel 1 output. |
| Output Ch. 2 | −80 to +10 dB | Adjusts the level of the analog Channel 2 output. |
| Dry/Wet | 0–100% | Crossfades the selected USB Return signal against its corresponding channel-fader signal. See [USB Signal Routing](#usb-signal-routing). |
| Return | −80 to +10 dB | Adjusts the level of the USB pair selected as the Return source. See [USB Signal Routing](#usb-signal-routing). |
| HP | −80 to +10 dB | Adjusts the headphone output level. |

## Magnetic-switch Assignments



The switches labeled `fade` provide behavior similar to the channel faders on a conventional DJ mixer. Instead of moving a physical fader, key travel changes a virtual fader position according to the current [fader curve setting](#fader-curve-settings). The A fade switches control Channel Fader A, and the B fade switches control Channel Fader B.

The following diagram shows the current magnetic-switch assignments.

### Magnetic-switch Functions

| Panel label | Function |
|---|---|
| A (B) fade down | Controls Channel Fader A (B) in the normal or reverse direction depending on whether the corresponding fade-up switch is held. See [Fade-down Direction](#fade-down-direction). |
| A (B) fade up | Moves Channel Fader A (B) from its current position toward full level. The response follows the corresponding channel-fader curve setting. |
| Aux. A/B (B/A) fade down | Provides an additional fade-down control assignable to Channel Fader A or B using JUMBLEQ Configurator. It follows the same direction behavior as the assigned fader's fade-down switch. See [Auxiliary Fade-down Switches](#auxiliary-fade-down-switches). |
| MIDI CC / Note (4 switches) | Sends MIDI CC 12–15 or Notes 68–71 on MIDI Ch. 1 with a linear response to key travel. The output mode is selected using JUMBLEQ Configurator. |

### Auxiliary Fade-down Switches



The two auxiliary fade-down switches can each be assigned to Channel Fader A or B using JUMBLEQ Configurator. By assigning both auxiliary switches to the same Channel Fader, that fader can be operated with up to three fade-down switches: its main fade-down switch plus the two auxiliary switches.

This arrangement makes rapid multi-click patterns easier to perform, including scratch techniques such as 3-click flares and crab scratches. By default, the A/B auxiliary switch is assigned to Channel Fader A, and the B/A auxiliary switch is assigned to Channel Fader B.

### Fader Curve Settings



The fader curve determines how the key travel of a fade switch is converted to the virtual fader position. Channel Faders A and B can be configured independently using JUMBLEQ Configurator.

| Setting | Response | Style |
|---|---|---|
| 0% | Late-rise response: most of the level change occurs near the end of the key travel. | Long-transition effects |
| 50% | Linear response across the full key travel. | Mixing |
| 100% | Early-rise response: the level rises sharply near the start of the key travel. | Scratching |

Intermediate settings follow a continuous exponential curve. The 0% and 100% responses are exact point reflections of one another around the 50% linear response. The corresponding curve applies to the fade-up and fade-down switches, including any auxiliary fade-down switch assigned to that Channel Fader.

### Fade-down Direction

The A and B fade-down switches change direction depending on whether the matching fade-up switch is held:

| Matching fade-up switch | Pressing fade down | Releasing fade down | Typical use |
|---|---|---|---|
| Not held | Moves the fader toward full level after soft takeover. | Returns the fader to mute after takeover. | Momentary fade-in |
| Held | Moves the fader toward mute. | Restores the level set by the held fade-up switch. | Momentary cut |

When fade up is not held, the fade-down switch uses reversed key travel: its released position represents mute, and pressing it deeper represents a higher level. Soft takeover prevents a sudden level jump by waiting until this reversed value reaches the current fader level before the switch takes control.

This behavior applies independently to Channel Faders A and B. An auxiliary fade-down switch follows the same behavior as the fader to which it is assigned.

See the [MIDI Transmit Specification](../reference/midi/transmit.md) for the MIDI output from all magnetic sensors.

## OLED Indications

The main OLED shows the current sample rate, input and output gains, Return status, and headphone level. The Return indication changes with the selected source:

| Return setting | OLED source indication |
|---|---|
| USB 1/2 | `RTN\|U12` |
| USB 3/4 | `RTN\|U34` |
| None | `RTN\|OFF` |

When USB 1/2 or USB 3/4 is selected, the Return gain is shown after the source indication. When Return is set to None, the gain field shows `---`.

The sub OLED shows the sources assigned to Channel Faders A and B, their input types and operating modes, the post-fader source, and the selected headphone-monitor source. `[D]` indicates DVS, `[S]` indicates SYNTH, and `[ ]` indicates Off for the assigned input channel.

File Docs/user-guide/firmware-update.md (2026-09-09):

# Firmware Update

JUMBLEQ includes a built-in UF2 bootloader, so application firmware can be updated without a dedicated programming tool.

## Enter UF2 Bootloader Mode

### Starting from Power Off

1. Make sure JUMBLEQ is powered off.
2. Hold down SW3.
3. While continuing to hold SW3, connect the USB cable.
4. Release SW3 after JUMBLEQ appears as a USB flash drive.

### While JUMBLEQ Is Running

1. Hold down SW3.
2. While continuing to hold SW3, press and release the RESET button.
3. Release SW3 after JUMBLEQ appears as a USB flash drive.

### From JUMBLEQ Configurator

Firmware v0.14.4 and later can safely prepare UF2 mode from the Web Configurator and clear both OLED displays before restarting:

1. Connect and synchronize JUMBLEQ in the Configurator.
2. In the **Device** section, select **Enter UF2 mode** and then **Arm UF2 mode**.
3. Within 10 seconds, release SW3 once and then hold it continuously for 2 seconds.
4. Keep holding SW3 until JUMBLEQ appears as a USB flash drive.

The Configurator request alone does not restart JUMBLEQ. The request is cancelled if SW3 is not confirmed within 10 seconds, the Configurator cancels it, or USB is disconnected. Unsaved settings are not stored automatically before the restart.

## Install Firmware

Drag and drop the JUMBLEQ `.uf2` firmware file onto the USB drive. The firmware update completes when the file copy finishes.

For information about generating UF2 files from an STM32CubeIDE project, see [Build and UF2 generation](../development/build-and-uf2.md).

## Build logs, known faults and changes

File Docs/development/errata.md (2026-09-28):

# STM32H7S3 Errata

## Erratum 2.2.15

ST documents the following STM32H7R/S device erratum:

- [I/O compensation could alter the duty cycle of a high-frequency output signal](https://www.st.com/resource/en/errata_sheet/es0596-stm32h7rxx7sxx-device-errata-stmicroelectronics.pdf)

The recommended workaround has already been implemented in the boot-side code:

- [`sbs.c`](../../STM32CubeIDE/MX25UW25645GXDI00_STM32H7S3Z8T/Boot/Core/Src/sbs.c)

## Erratum 2.2.17

[ES0596 Rev 10, section 2.2.17](https://www.st.com/resource/en/errata_sheet/es0596-stm32h7rxx7sxx-device-errata-stmicroelectronics.pdf)
describes a system hang on access to `0x25000000`–`0x25FFFFFF`, including
speculative accesses and devices without GFXMMU.

Both the application-side [`main.c`](../../STM32CubeIDE/JUMBLEQ/Appli/Core/Src/main.c)
and the Boot-side [`main.c`](../../STM32CubeIDE/MX25UW25645GXDI00_STM32H7S3Z8T/Boot/Core/Src/main.c)
configure this unused range as MPU Region 4 with Strongly-ordered, no-access
and execute-never attributes before enabling the CPU caches. DMA completion
diagnostics and the existing cache settings remain enabled.

The user confirmed at least six hours of continuous operation with the
application-only comparison UF2, without a freeze. Audio, LEDs, OLED/UI,
volume and mute operations were reported normal, meeting the agreed test
criterion.

The user then built and programmed Boot and App through STM32CubeIDE. The
generated Boot Release ELF was inspected and contained the same MPU protection
before cache enable. The Boot+App configuration ran overnight without a freeze;
audio/UI, volume/mute, power cycling, UF2 mode and transition to the application
were all reported normal on 2026-09-29.

These results meet the agreed hardware test criterion and support the
workaround, but do not directly prove which speculative access caused the
original freeze. App UF2 programming alone does not update Boot. The current
App Release (STLINK) Run configuration downloads Boot without automatically
building it, so Boot must be rebuilt separately before programming changes.

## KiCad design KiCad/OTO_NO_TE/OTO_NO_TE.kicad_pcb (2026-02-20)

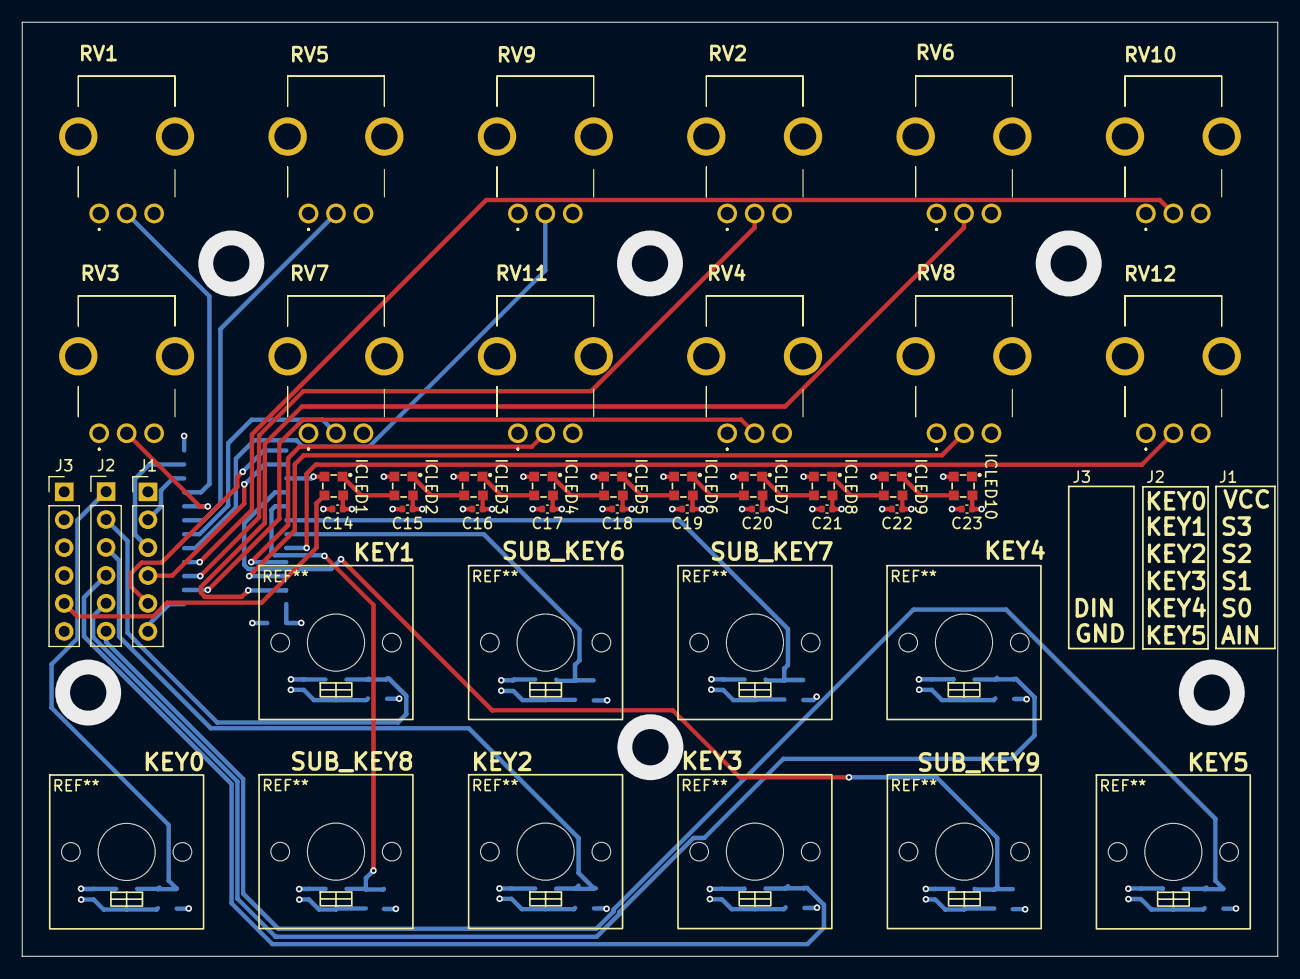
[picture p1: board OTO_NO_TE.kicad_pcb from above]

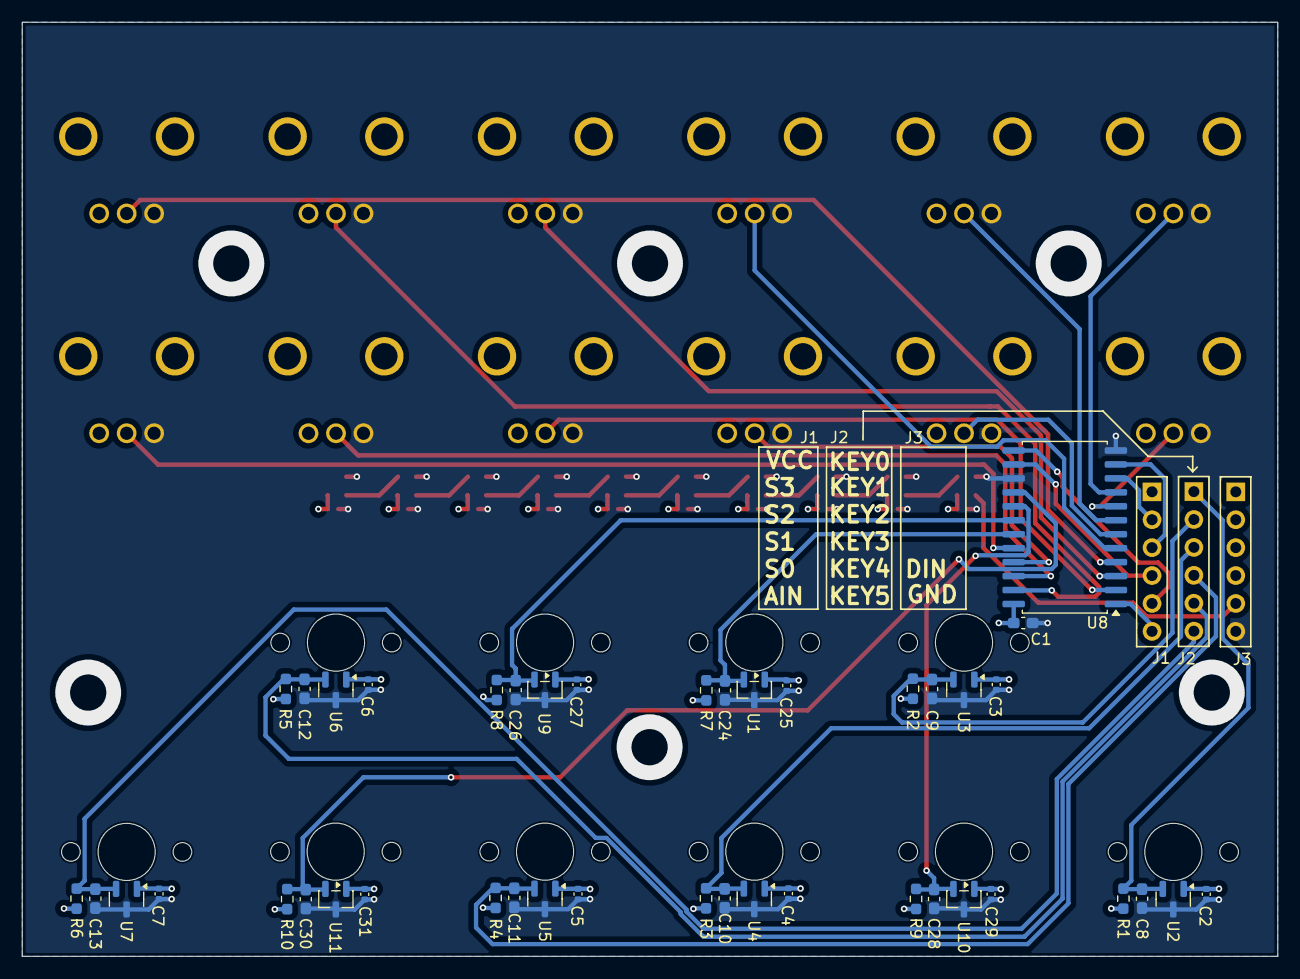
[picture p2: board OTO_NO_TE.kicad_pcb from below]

Board: 4 copper layers, 114.3 x 85.0 mm, 77 parts (42 on the bottom side), 39 nets.

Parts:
C1: 100nF; C_0603_1608Metric_Pad1.08x0.95mm_HandSolder
C2, C3, C4, C5, C6, C7, C25, C27, C29, C31: 10nF; C_0402_1005Metric
C8, C9, C10, C11, C12, C13, C24, C26, C28, C30: C_0603_1608Metric_Pad1.08x0.95mm_HandSolder
C14, C15, C16, C17, C18, C19, C20, C21, C22, C23: 100nF; C_0402_1005Metric
ICLED1, ICLED2, ICLED3, ICLED4, ICLED5, ICLED6, ICLED7, ICLED8, ICLED9, ICLED10: 1312020030000
J1, J2, J3: Conn_01x06; PinHeader_1x06_P2.54mm_Vertical
R1, R2, R3, R4, R5, R6, R7, R8, R9, R10: R_0603_1608Metric_Pad0.98x0.95mm_HandSolder
RV1, RV2, RV3, RV4, RV5, RV6, RV7, RV8, RV9, RV10, RV11, RV12: 10k; RK09K1130A5R
U1, U2, U3, U4, U5, U6, U7, U9, U10, U11: DRV5056A3QDBZR; SOT-23
U8: CD74HC4067M; SOIC-24W_7.5x15.4mm_P1.27mm

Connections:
/KEY0: C8.1, J2.1, R1.2, U2.2 (OUT)
/KEY1: C9.1, J2.2, R2.2, U3.2 (OUT)
/KEY2: C10.1, J2.3, R3.2, U4.2 (OUT)
/KEY3: C11.1, J2.4, R4.2, U5.2 (OUT)
/KEY4: C12.1, J2.5, R5.2, U6.2 (OUT)
/KEY5: C13.1, J2.6, R6.2, U7.2 (OUT)
/KEY6: C24.1, R7.2, U1.2 (OUT), U8.19 (I12)
/KEY7: C26.1, R8.2, U8.18 (I13), U9.2 (OUT)
/KEY8: C28.1, R9.2, U8.17 (I14), U10.2 (OUT)
/KEY9: C30.1, R10.2, U8.16 (I15), U11.2 (OUT)
/L0: RV1.2, U8.9 (I0)
/L1: RV3.2, U8.8 (I1)
/L2: RV5.2, U8.7 (I2)
/L3: RV7.2, U8.6 (I3)
/L4: RV9.2, U8.5 (I4)
/L5: RV10.2, U8.4 (I5)
/LEDs/DIN: ICLED1.3 (DIN), J3.5
/R0: RV2.2, U8.3 (I6)
/R1: RV4.2, U8.2 (I7)
/R2: RV6.2, U8.23 (I8)
/R3: RV8.2, U8.22 (I9)
/R4: RV11.2, U8.21 (I10)
/R5: RV12.2, U8.20 (I11)
GND: C1.2, C2.2, C3.2, C4.2, C5.2, C6.2, C7.2, C8.2, C9.2, C10.2, C11.2, C12.2, C13.2, C14.2, C15.2, C16.2, C17.2, C18.2, C19.2, C20.2, C21.2, C22.2, C23.2, C24.2, C25.2, C26.2, C27.2, C28.2, C29.2, C30.2, C31.2, ICLED1.4 (VSS), ICLED2.4 (VSS), ICLED3.4 (VSS), ICLED4.4 (VSS), ICLED5.4 (VSS), ICLED6.4 (VSS), ICLED7.4 (VSS), ICLED8.4 (VSS), ICLED9.4 (VSS), ICLED10.4 (VSS), J3.6, RV1.1, RV2.1, RV3.1, RV4.1, RV5.1, RV6.1, RV7.1, RV8.1, RV9.1, RV10.1, RV11.1, RV12.1, U1.3 (GND), U2.3 (GND), U3.3 (GND), U4.3 (GND), U5.3 (GND), U6.3 (GND), U7.3 (GND), U8.12 (GND), U8.15 (~E), U9.3 (GND), U10.3 (GND), U11.3 (GND)
unnamed: ICLED1.1 (DOUT), ICLED2.3 (DIN)
unnamed: ICLED2.1 (DOUT), ICLED3.3 (DIN)
unnamed: ICLED3.1 (DOUT), ICLED4.3 (DIN)
unnamed: ICLED4.1 (DOUT), ICLED5.3 (DIN)
unnamed: ICLED5.1 (DOUT), ICLED6.3 (DIN)
unnamed: ICLED6.1 (DOUT), ICLED7.3 (DIN)
unnamed: ICLED7.1 (DOUT), ICLED8.3 (DIN)
unnamed: ICLED8.1 (DOUT), ICLED9.3 (DIN)
unnamed: ICLED9.1 (DOUT), ICLED10.3 (DIN)
unnamed: J1.2, U8.10 (S0)
unnamed: J1.3, U8.11 (S1)
unnamed: J1.4, U8.14 (S2)
unnamed: J1.5, U8.13 (S3)
unnamed: J1.6, U8.1 (COM)
VCC: C1.1, C2.1, C3.1, C4.1, C5.1, C6.1, C7.1, C14.1, C15.1, C16.1, C17.1, C18.1, C19.1, C20.1, C21.1, C22.1, C23.1, C25.1, C27.1, C29.1, C31.1, ICLED1.2 (VDD), ICLED2.2 (VDD), ICLED3.2 (VDD), ICLED4.2 (VDD), ICLED5.2 (VDD), ICLED6.2 (VDD), ICLED7.2 (VDD), ICLED8.2 (VDD), ICLED9.2 (VDD), ICLED10.2 (VDD), J1.1, R1.1, R2.1, R3.1, R4.1, R5.1, R6.1, R7.1, R8.1, R9.1, R10.1, RV1.3, RV2.3, RV3.3, RV4.3, RV5.3, RV6.3, RV7.3, RV8.3, RV9.3, RV10.3, RV11.3, RV12.3, U1.1 (VCC), U2.1 (VCC), U3.1 (VCC), U4.1 (VCC), U5.1 (VCC), U6.1 (VCC), U7.1 (VCC), U8.24 (VCC), U9.1 (VCC), U10.1 (VCC), U11.1 (VCC)

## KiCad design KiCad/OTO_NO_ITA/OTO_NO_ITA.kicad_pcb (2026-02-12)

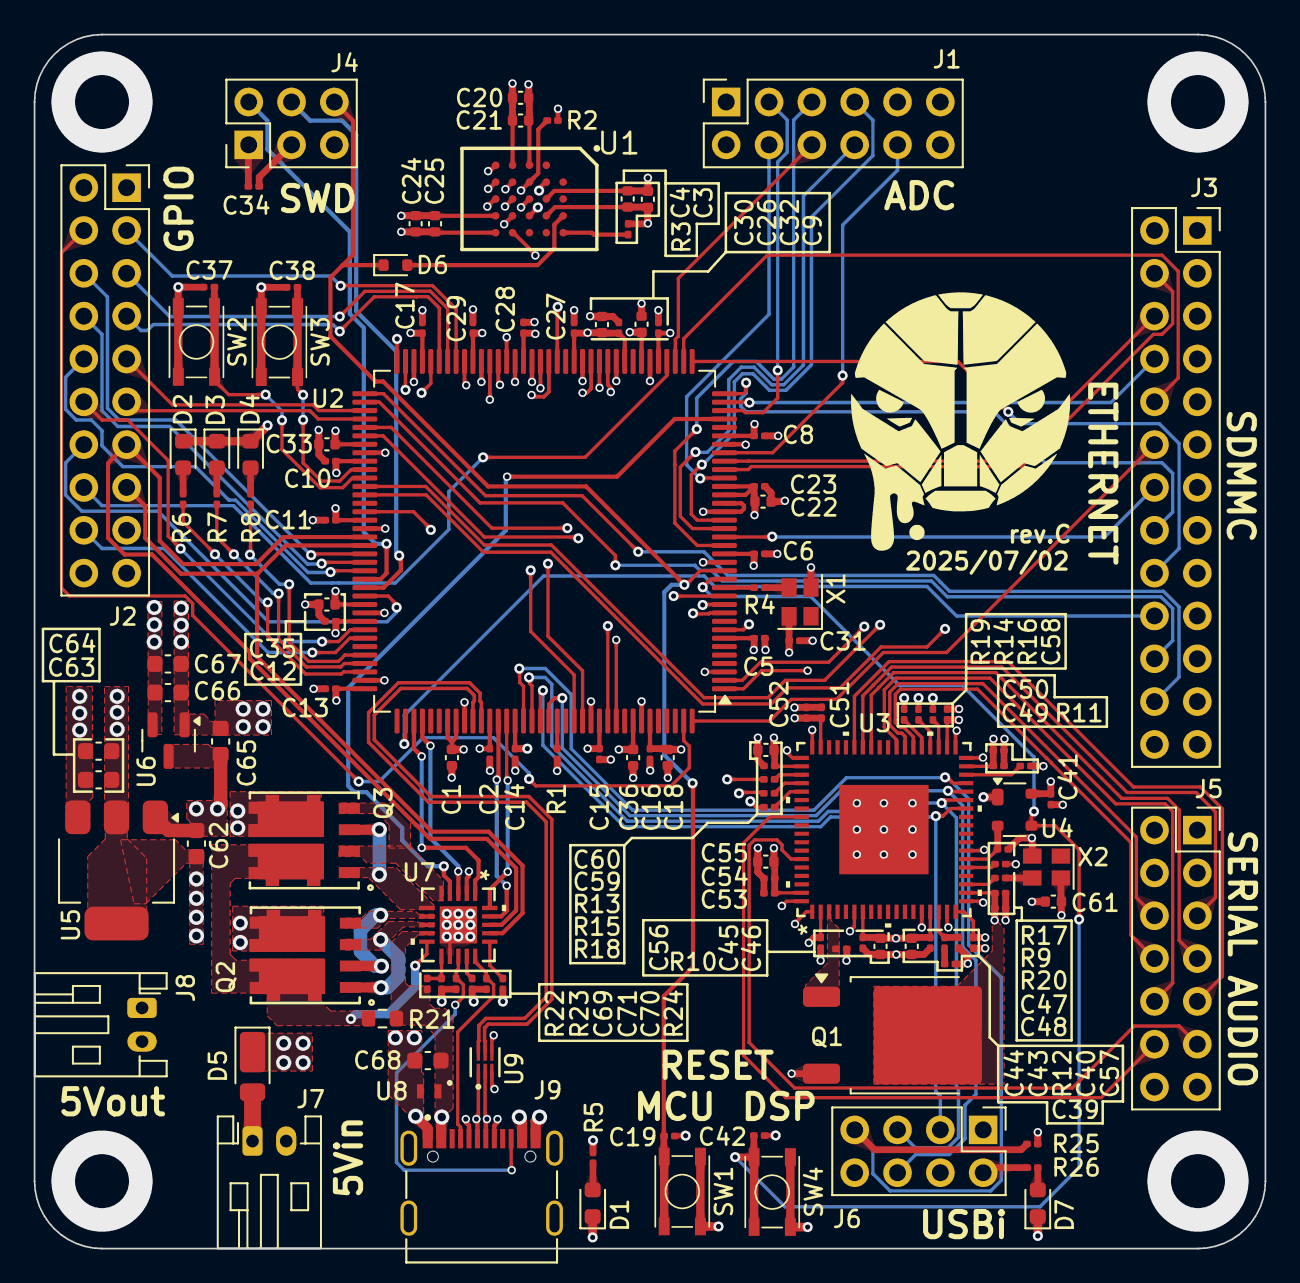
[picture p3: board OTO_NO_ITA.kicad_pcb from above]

Board: 6 copper layers, 73.0 x 72.0 mm, 130 parts (0 on the bottom side), 135 nets.

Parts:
C1, C22: 1uF; C_0402_1005Metric
C2, C5, C6, C8, C9, C10, C11, C12, C13, C14, C15, C16, C17, C19, C23, C26, C27, C28, C29, C31, C34, C37, C38, C41, C42, C43, C45, C48, C50, C52, C54, C56, C57, C58, C59, C71: 100nF; C_0201_0603Metric
C3, C18, C20, C24, C30: 4.7uF; C_0402_1005Metric
C4, C21, C25, C61: 100nF; C_0402_1005Metric
C32, C33, C35, C36: 2.2uF; C_0402_1005Metric
C39: 5.6nF; C_0201_0603Metric
C40: 150pF; C_0201_0603Metric
C44, C46, C55, C60: 10uF; C_0402_1005Metric
C47, C49, C51, C53: 10nF; C_0201_0603Metric
C62, C63, C64: 4.7uF; C_0603_1608Metric
C65, C66, C67: 1uF; C_0603_1608Metric
C68: 2.2uF/50V; C_0603_1608Metric
C69, C70: 560pF; C_0201_0603Metric
D1, D2, D3, D4, D7: LED; LED_0603_1608Metric
D5: D_Schottky; D_PowerDI-123
D6: D_Schottky; D_SOD-523
J1: Conn_02x06_Odd_Even; PinSocket_2x06_P2.54mm_Vertical
J2: Conn_02x10_Odd_Even; PinSocket_2x10_P2.54mm_Vertical
J3: Conn_02x13_Odd_Even; PinSocket_2x13_P2.54mm_Vertical
J4: 15910060; PinHeader_2x03_P2.54mm_Vertical
J5: Conn_02x07_Odd_Even; PinSocket_2x07_P2.54mm_Vertical
J6: Conn_02x04_Odd_Even; PinHeader_2x04_P2.54mm_Vertical
J7, J8: Conn_01x02; JST_PH_S2B-PH-K_1x02_P2.00mm_Horizontal
J9: UB1611-HGN; Gangyuan_UB1611-HGN
Q1: STD2805T4; TO-252-2
Q2, Q3: STL40DN3LLH5; SON_DN3LLH5_STM
R1, R2, R3, R11, R22, R24, R25: 10k; R_0201_0603Metric
R4, R9, R13, R14, R15, R16, R18, R19, R20: 33R; R_0201_0603Metric
R5, R6, R7, R8, R10, R26: 1k; R_0201_0603Metric
R12: 4.32k; R_0201_0603Metric
R17: 100k; R_0201_0603Metric
R21: 22mR; R_0603_1608Metric
R23: 2k4; R_0201_0603Metric
SW1, SW2, SW3, SW4: SKRPABE010
U1: MX25UW25645GXDI00; BGA24C100P5X5_800X600X120
U2: STM32H7S3Z8Tx; LQFP-144_20x20mm_P0.5mm
U3: ADAU1466WBCPZ300RL; CP_72_6_ADI
U4: ADM811TARTZ; SOT-143
U5: AP7361EA-33E-13; SOT-223-3_TabPin2
U6: AP2127N-1.8TRG1; SOT-23
U7: TCPP03-M20; QFN-20L_4.0X4.0X0.75_STM
U8: ESDA25P35-1U1M; QFN1610_STM
U9: ECMF2-40A100N6; QFN6L_ECMF2_STM
X1: 24MHz; Oscillator_SMD_SeikoEpson_SG210-4Pin_2.5x2.0mm
X2: 12.288MHz; Oscillator_SMD_SeikoEpson_SG210-4Pin_2.5x2.0mm

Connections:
1V8: C3.2, C4.2, C20.2, C21.2, C24.2, C25.2, C26.2, C27.2, C28.2, C29.2, C30.2, C66.1, C67.1, R2.2, R3.1, U1.B4 (VCC), U1.D1 (VCCQ), U1.E4 (VCCQ), U2.45 (VDDXSPI1), U2.51 (VDDXSPI1), U2.57 (VDDXSPI1), U2.63 (VDDXSPI1), U6.2 (VO)
3V3: C1.2, C5.2, C6.2, C8.2, C9.2, C10.2, C11.2, C12.2, C13.2, C14.2, C15.2, C16.2, C17.2, C18.2, C22.2, C23.2, C31.2, C34.2, C39.2, C40.1, C41.1, C43.1, C44.1, C45.1, C46.1, C56.1, C57.1, C58.1, C59.1, C60.1, C61.2, C63.1, C64.1, J1.1, J1.2, J2.1, J2.2, J3.1, J3.2, J4.1, J5.1, J5.2, Q1.3 (E), R5.1, R10.1, R25.2, U2.3 (VBAT), U2.7 (VDD), U2.17 (VDD), U2.24 (VREFP), U2.25 (VDDA), U2.31 (VDD), U2.41 (VDD), U2.69 (VDD), U2.81 (VDD), U2.88 (VDD), U2.100 (VDD), U2.108 (VDD), U2.115 (VDD50USB), U2.116 (VDD33USB), U2.123 (VDD), U2.133 (VDD), U2.139 (VDD), U3.2 (IOVDD), U3.7 (AVDD), U3.15 (PVDD), U3.18 (IOVDD), U3.38 (IOVDD), U3.56 (IOVDD), U4.4 (VCC), U5.3 (VO), U7.2 (VCC_VCONN), X1.4 (Vcc), X2.4 (Vcc)
5V: D5.1 (K), Q3.5 (D1), Q3.6 (D1)
5V_UCPD: C62.1, C65.1, J8.1, Q2.5 (D1), Q2.6 (D1), U5.1 (VI), U6.3 (VI)
/DSP/BCLK_OUT1: J5.6, U3.43 (BCLK_OUT1)
/DSP/BCLK_OUT2: J5.5, U3.48 (BCLK_OUT2)
/DSP/CLKOUT: J5.3, J5.4, R9.2, U2.87 (PC9)
/DSP/DSP_BCLK_IN0: R13.1, U2.72 (PD13)
/DSP/DSP_BCLK_OUT0: R14.1, U2.11 (PE5)
/DSP/DSP_LRCLK_IN0: R15.1, U2.71 (PD12)
/DSP/DSP_LRCLK_OUT0: R16.1, U2.10 (PE4)
/DSP/DSP_RESET: C42.1, SW4.1, SW4.2, U2.14 (PH1), U4.3 (~MR)
/DSP/DSP_SDATA_IN0: R18.1, U2.68 (PD11)
/DSP/DSP_SDATA_OUT0: R19.1, U2.12 (PE6)
/DSP/LRCLK_OUT1: J5.8, U3.42 (LRCLK_OUT1/MP5)
/DSP/LRCLK_OUT2: J5.7, U3.47 (LRCLK_OUT2/MP8)
/DSP/MCLK: R20.2, U3.21 (XTALIN/MCLK)
/DSP/SDATA_IN1: J5.12, U3.62 (SDATA_IN1)
/DSP/SDATA_IN2: J5.11, U3.67 (SDATA_IN2)
/DSP/SDATA_OUT1: J5.10, U3.44 (SDATA_OUT1)
/DSP/SDATA_OUT2: J5.9, U3.49 (SDATA_OUT2)
/DSP/USBi_MISO: J6.3, U2.126 (PM14), U3.30 (MISO/SDA)
/DSP/USBi_MOSI: J6.6, U2.127 (PM13), U3.32 (MOSI/ADDR1)
/DSP/USBi_SCLK: J6.5, U2.125 (PM11), U3.31 (SCLKC/SCL)
/DSP/USBi_SS: J6.7, R25.1, U2.124 (PM12), U3.33 (SS/ADDR0)
/DSP/~RESET: R17.2, U3.24 (RESET*), U4.2 (~RESET)
/MCU/ADC1_IN0: J1.4, U2.26 (PA0)
/MCU/ADC1_IN3: J1.3, U2.34 (PA6)
/MCU/ADC1_IN5: J1.6, U2.39 (PB1)
/MCU/ADC1_IN10: J1.5, U2.18 (PC0)
/MCU/ADC1_IN12: J1.8, U2.20 (PC2)
/MCU/ADC1_IN13: J1.7, U2.21 (PC3)
/MCU/ADC1_IN15: J1.10, U2.29 (PA3)
/MCU/DEBUG_SWCLK: J4.4, U2.96 (PA14(JTCK)
/MCU/DEBUG_SWDIO: J4.2, U2.95 (PA13(JTMS)
/MCU/ETH_MDC: J3.14, U2.19 (PC1)
/MCU/ETH_MDIO: J3.6, U2.28 (PA2)
/MCU/ETH_MII_RX_ER: J3.24, U2.73 (PB10)
/MCU/ETH_RMII_CRS_DV: J3.8, U2.35 (PA7)
/MCU/ETH_RMII_INTN: J3.20, U2.110 (PD4)
/MCU/ETH_RMII_REF_CLK: J3.4, U2.27 (PA1)
/MCU/ETH_RMII_RXD0: J3.16, U2.36 (PC4)
/MCU/ETH_RMII_RXD1: J3.18, U2.37 (PC5)
/MCU/ETH_RMII_TXD0: J3.10, U2.38 (PB0)
/MCU/ETH_RMII_TXD1: J3.12, U2.144 (PB7)
/MCU/ETH_RMII_TX_EN: J3.22, U2.74 (PB11)
/MCU/FDCAN2_RX: J2.9, U2.75 (PB12)
/MCU/FDCAN2_TX: J2.11, U2.76 (PB13)
/MCU/I2C2_SCL: J2.13, U2.90 (PA8), U7.18 (SCL)
/MCU/I2C2_SDA: J2.15, U2.91 (PA9), U7.17 (SDA)
/MCU/I2S3_CK: J2.12, U2.101 (PC10)
/MCU/I2S3_SDI: J2.18, U2.102 (PC11)
/MCU/I2S3_SDO: J2.16, U2.40 (PB2)
/MCU/I2S3_WS: J2.14, U2.97 (PA15(JTDI))
/MCU/LED0: R6.1, U2.106 (PD2)
/MCU/LED1: R7.1, U2.105 (PD1)
/MCU/LED2: R8.1, U2.104 (PD0)
/MCU/LPUART1_CTS: J2.8, U2.93 (PA11)
/MCU/LPUART1_RTS: J2.10, U2.94 (PA12)
/MCU/LPUART1_RX: J2.6, U2.92 (PA10)
/MCU/LPUART1_TX: J2.4, U2.143 (PB6)
/MCU/NRST: C19.2, D6.1 (K), J4.6, SW1.3 (K), SW1.4 (A), U2.15 (NRST)
/MCU/OSPI_CS: R2.1, U1.C2 (CS), U2.64 (PO0)
/MCU/OSPI_DQS: U1.C3 (DQS), U2.59 (PO2)
/MCU/OSPI_SCLK: U1.B2 (SCLK), U2.53 (PO4)
/MCU/OSPI_SIO0: U1.D3 (SIO0), U2.55 (PP0)
/MCU/OSPI_SIO1: U1.D2 (SIO1), U2.61 (PP1)
/MCU/OSPI_SIO2: U1.C4 (SIO2), U2.48 (PP2)
/MCU/OSPI_SIO3: U1.D4 (SIO3), U2.49 (PP3)
/MCU/OSPI_SIO4: U1.D5 (SIO4), U2.47 (PP4)
/MCU/OSPI_SIO5: U1.E3 (SIO5), U2.54 (PP5)
/MCU/OSPI_SIO6: U1.E2 (SIO6), U2.58 (PP6)
/MCU/OSPI_SIO7: U1.E1 (SIO7), U2.60 (PP7)
/MCU/SDMMC2_CK: J3.3, U2.130 (PD6)
/MCU/SDMMC2_CMD: J3.5, U2.131 (PD7)
/MCU/SDMMC2_D0: J3.7, U2.77 (PB14)
/MCU/SDMMC2_D1: J3.9, U2.78 (PB15)
/MCU/SDMMC2_D2: J3.11, U2.134 (PB3(JTDO)
/MCU/SDMMC2_D3: J3.13, U2.135 (PB4(NJTRST))
/MCU/SDMMC2_D4: J3.15, U2.1 (PB8)
/MCU/SDMMC2_D5: J3.17, U2.2 (PB9)
/MCU/SDMMC2_D6: J3.19, U2.84 (PC6)
/MCU/SDMMC2_D7: J3.21, U2.85 (PC7)
/MCU/UCPD_CC1: U2.111 (PM0), U7.1 (CC1)
/MCU/UCPD_CC2: U2.112 (PM1), U7.3 (CC2)
/MCU/UCPD_INT: U2.121 (PM8), U7.19 (FLG_n)
/MCU/UCPD_ISENSE: U2.33 (PA5), U7.4 (I_ANA)
/MCU/UCPD_PWR_EN: U2.122 (PM9), U7.20 (EN)
/MCU/USART3_CK: J2.7, U2.67 (PD10)
/MCU/USART3_RX: J2.5, U2.66 (PD9)
/MCU/USART3_TX: J2.3, U2.65 (PD8)
/MCU/USB_HS_D+: U2.119 (PM6), U9.6 (D+_ic)
/MCU/USB_HS_D-: U2.118 (PM5), U9.5 (D-_ic)
/MCU/USER_SW1: C37.2, SW2.3 (K), SW2.4 (A), U2.83 (PD15)
/MCU/USER_SW2: C38.2, SW3.3 (K), SW3.4 (A), U2.82 (PD14)
/USB/CC1: C70.1, J9.A5 (CC1), U7.15 (CC_1c)
/USB/CC2: C69.1, J9.B5 (CC2), U7.13 (CC_2c)
/USB/D+: J9.A6 (DP1), J9.B6 (DP2), U9.1 (D+_con)
/USB/D-: J9.A7 (DN1), J9.B7 (DN2), U9.2 (D-_con)
DVDD: C47.1, C48.1, C49.1, C50.1, C51.1, C52.1, C53.1, C54.1, C55.1, Q1.2 (C), U3.20 (DVDD), U3.35 (DVDD), U3.53 (DVDD), U3.71 (DVDD)
GND: C1.1, C2.1, C3.1, C4.1, C5.1, C6.1, C8.1, C9.1, C10.1, C11.1, C12.1, C13.1, C14.1, C15.1, C16.1, C17.1, C18.1, C19.1, C20.1, C21.1, C22.1, C23.1, C24.1, C25.1, C26.1, C27.1, C28.1, C29.1, C30.1, C31.1, C32.1, C33.1, C34.1, C35.1, C36.1, C37.1, C38.1, C41.2, C42.2, C43.2, C44.2, C45.2, C46.2, C47.2, C48.2, C49.2, C50.2, C51.2, C52.2, C53.2, C54.2, C55.2, C56.2, C57.2, C58.2, C59.2, C60.2, C61.1, C62.2, C63.2, C64.2, C65.2, C66.2, C67.2, C68.2, C69.2, C70.2, C71.2, D1.1 (K), D2.1 (K), D3.1 (K), D4.1 (K), D7.1 (K), J1.9, J1.11, J1.12, J2.17, J2.19, J2.20, J3.23, J3.25, J3.26, J4.3, J4.5, J5.13, J5.14, J6.8, J7.2, J8.2, J9.A1_B12 (GND), J9.B1_A12 (GND), J9.S1 (SHIELD), J9.S2 (SHIELD), J9.S3 (SHIELD), J9.S4 (SHIELD), R1.1, R11.1, R17.1, R23.2, R24.2, SW1.1, SW1.2, SW2.1, SW2.2, SW3.1, SW3.2, SW4.3 (K), SW4.4 (A), U1.B3 (GND), U1.C1 (VSSQ), U1.E5 (VSSQ), U2.8 (VSS), U2.16 (VSS), U2.22 (VSSA), U2.23 (VREFM), U2.30 (VSS), U2.42 (VSS), U2.46 (VSS), U2.50 (VSS), U2.56 (VSS), U2.62 (VSS), U2.70 (VSS), U2.80 (VSS), U2.89 (VSS), U2.99 (VSS), U2.107 (VSS), U2.117 (VSSUSB), U2.132 (VSS), U2.138 (VSS), U3.1 (DGND), U3.6 (AGND), U3.14 (PGND), U3.17 (DGND), U3.19 (DGND), U3.25 (DGND), U3.36 (DGND), U3.37 (DGND), U3.54 (DGND), U3.55 (DGND), U3.72 (DGND), U3.73 (EP(GND)), U4.1 (GND), U5.2 (GND), U6.1 (GND), U7.12 (GND), U7.21 (GND), U8.2, U9.3 (GND), U9.4 (GND), X1.2 (GND), X2.2 (GND)
MCU_DVDD: C2.2, C32.2, C33.2, C35.2, C36.2, U2.43 (VCAP1), U2.79 (VCAP2), U2.98 (VCAP3), U2.120 (DVDD), U2.137 (VCAP4)
unnamed: C39.1, R12.1
unnamed: D1.2 (A), R5.2
unnamed: D2.2 (A), R6.2
unnamed: D3.2 (A), R7.2
unnamed: D4.2 (A), R8.2
unnamed: D5.2 (A), J7.1
unnamed: D6.2 (A), U1.A4 (RESET)
unnamed: D7.2 (A), R26.2
unnamed: J6.2, R26.1
unnamed: Q1.1 (B), R10.2, U3.3 (VDRIVE)
unnamed: Q2.2 (G2), Q2.4 (G1), U7.7 (GDC_g)
unnamed: Q2.1 (S2), Q2.3 (S1), U7.8 (GDC_s)
unnamed: Q3.2 (G2), Q3.4 (G1), U7.5 (GDP_g)
unnamed: Q3.1 (S2), Q3.3 (S1), U7.6 (GDP_s)
unnamed: R3.2, U1.A5 (ECS)
unnamed: R1.2, U2.128 (BOOT0)
unnamed: R4.2, U2.13 (PH0)
unnamed: R13.2, U3.57 (BCLK_IN0)
unnamed: R14.2, U3.40 (BCLK_OUT0)
unnamed: R9.1, U3.23 (CLKOUT)
unnamed: R15.2, U3.58 (LRCLK_IN0/MP10)
unnamed: R16.2, U3.39 (LRCLK_OUT0/MP4)
unnamed: C40.2, R12.2, U3.16 (PLLFILT)
unnamed: R18.2, U3.59 (SDATA_IN0)
unnamed: R19.2, U3.41 (SDATA_OUT0)
unnamed: R11.2, U3.34 (SELFBOOT)
unnamed: C71.1, U7.14 (C_BIAS)
unnamed: R24.1, U7.16 (I2C_ADD)
unnamed: Q2.7 (D2), Q2.8 (D2), Q3.7 (D2), Q3.8 (D2), R21.1, U7.10 (I_SENSE)
unnamed: R22.2, R23.1, U7.11 (V_SENSE)
unnamed: R4.1, X1.3 (OUT)
unnamed: R20.1, X2.3 (OUT)
VBUS: C68.1, J9.A4_B9 (VBUS), J9.B4_A9 (VBUS), R21.2, R22.1, U7.9 (VBUS_c), U8.1

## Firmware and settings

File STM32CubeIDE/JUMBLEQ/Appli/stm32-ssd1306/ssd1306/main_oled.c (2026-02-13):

#include <main_oled.h>
#include <math.h>
#include <stdlib.h>
#include <string.h>  // For memcpy

#include "cmsis_os2.h"
#include "FreeRTOS.h"
#include "semphr.h"

// I2C排他制御用ミューテックス
extern osMutexId_t i2cMutexHandle;

static uint8_t main_oled_cmd_byte = 0;  // コマンド用バッファ

#if defined(MAIN_OLED_USE_I2C)

// I2C送信（ブロッキングモード、排他制御付き）
static HAL_StatusTypeDef main_oled_I2C_Write(uint16_t mem_addr, uint8_t* data, uint16_t size)
{
    HAL_StatusTypeDef status = HAL_ERROR;

    if (i2cMutexHandle == NULL)
    {
        return HAL_ERROR;
    }

    // ミューテックスで排他制御（最大200ms待機）
    if (osMutexAcquire(i2cMutexHandle, pdMS_TO_TICKS(200)) == osOK)
    {
        // ブロッキングモードで送信（タイムアウト100ms）
        status = HAL_I2C_Mem_Write(&MAIN_OLED_I2C_PORT, MAIN_OLED_I2C_ADDR, mem_addr, 1, data, size, 100);

        osMutexRelease(i2cMutexHandle);
    }

    return status;
}

void main_oled_Reset(void)
{
    /* for I2C - do nothing */
}

// Send a byte to the command register
void main_oled_WriteCommand(uint8_t byte)
{
    main_oled_cmd_byte = byte;  // staticバッファにコピー
    main_oled_I2C_Write(0x00, &main_oled_cmd_byte, 1);
}

// Send data
void main_oled_WriteData(uint8_t* buffer, size_t buff_size)
{
    main_oled_I2C_Write(0x40, buffer, (uint16_t) buff_size);
}

#elif defined(MAIN_OLED_USE_SPI)

void main_oled_Reset(void)
{
    // CS = High (not selected)
    HAL_GPIO_WritePin(MAIN_OLED_CS_Port, MAIN_OLED_CS_Pin, GPIO_PIN_SET);

    // Reset the OLED
    HAL_GPIO_WritePin(MAIN_OLED_Reset_Port, MAIN_OLED_Reset_Pin, GPIO_PIN_RESET);
    HAL_Delay(10);
    HAL_GPIO_WritePin(MAIN_OLED_Reset_Port, MAIN_OLED_Reset_Pin, GPIO_PIN_SET);
    HAL_Delay(10);
}

// Send a byte to the command register
void main_oled_WriteCommand(uint8_t byte)
{
    HAL_GPIO_WritePin(MAIN_OLED_CS_Port, MAIN_OLED_CS_Pin, GPIO_PIN_RESET);  // select OLED
    HAL_GPIO_WritePin(MAIN_OLED_DC_Port, MAIN_OLED_DC_Pin, GPIO_PIN_RESET);  // command
    HAL_SPI_Transmit(&MAIN_OLED_SPI_PORT, (uint8_t*) &byte, 1, HAL_MAX_DELAY);
    HAL_GPIO_WritePin(MAIN_OLED_CS_Port, MAIN_OLED_CS_Pin, GPIO_PIN_SET);  // un-select OLED
}

// Send data
void main_oled_WriteData(uint8_t* buffer, size_t buff_size)
{
    HAL_GPIO_WritePin(MAIN_OLED_CS_Port, MAIN_OLED_CS_Pin, GPIO_PIN_RESET);  // select OLED
    HAL_GPIO_WritePin(MAIN_OLED_DC_Port, MAIN_OLED_DC_Pin, GPIO_PIN_SET);    // data
    HAL_SPI_Transmit(&MAIN_OLED_SPI_PORT, buffer, buff_size, HAL_MAX_DELAY);
    HAL_GPIO_WritePin(MAIN_OLED_CS_Port, MAIN_OLED_CS_Pin, GPIO_PIN_SET);  // un-select OLED
}

#else
    #error "You should define MAIN_OLED_USE_SPI or MAIN_OLED_USE_I2C macro"
#endif

// Screenbuffer
static uint8_t MAIN_OLED_Buffer[MAIN_OLED_BUFFER_SIZE];

// Screen object
static MAIN_OLED_t MAIN_OLED;

/* Fills the Screenbuffer with values from a given buffer of a fixed length */
SSD1306_Error_t main_oled_FillBuffer(uint8_t* buf, uint32_t len)
{
    SSD1306_Error_t ret = SSD1306_ERR;
    if (len <= MAIN_OLED_BUFFER_SIZE)
    {
        memcpy(MAIN_OLED_Buffer, buf, len);
        ret = SSD1306_OK;
    }
    return ret;
}

/* Initialize the oled screen */
void main_oled_Init(void)
{
    // Reset OLED
    main_oled_Reset();

    // Wait for the screen to boot
    HAL_Delay(100);

    // Init OLED
    main_oled_SetDisplayOn(0);  // display off

    main_oled_WriteCommand(0x20);  // Set Memory Addressing Mode
    main_oled_WriteCommand(0x00);  // 00b,Horizontal Addressing Mode; 01b,Vertical Addressing Mode;
                                   // 10b,Page Addressing Mode (RESET); 11b,Invalid

    main_oled_WriteCommand(0xB0);  // Set Page Start Address for Page Addressing Mode,0-7

#ifdef MAIN_OLED_MIRROR_VERT
    main_oled_WriteCommand(0xC0);  // Mirror vertically
#else
    main_oled_WriteCommand(0xC8);  // Set COM Output Scan Direction
#endif

    main_oled_WriteCommand(0x00);  //---set low column address
    main_oled_WriteCommand(0x10);  //---set high column address

    main_oled_WriteCommand(0x40);  //--set start line address - CHECK

    main_oled_SetContrast(0xFF);

#ifdef MAIN_OLED_MIRROR_HORIZ
    main_oled_WriteCommand(0xA0);  // Mirror horizontally
#else
    main_oled_WriteCommand(0xA1);  //--set segment re-map 0 to 127 - CHECK
#endif

#ifdef MAIN_OLED_INVERSE_COLOR
    main_oled_WriteCommand(0xA7);  //--set inverse color
#else
    main_oled_WriteCommand(0xA6);  //--set normal color
#endif

// Set multiplex ratio.
#if (MAIN_OLED_HEIGHT == 128)
    // Found in the Luma Python lib for SH1106.
    main_oled_WriteCommand(0xFF);
#else
    main_oled_WriteCommand(0xA8);  //--set multiplex ratio(1 to 64) - CHECK
#endif

#if (MAIN_OLED_HEIGHT == 32)
    main_oled_WriteCommand(0x1F);  //
#elif (MAIN_OLED_HEIGHT == 64)
    main_oled_WriteCommand(0x3F);  //
#elif (MAIN_OLED_HEIGHT == 128)
    main_oled_WriteCommand(0x3F);  // Seems to work for 128px high displays too.
#else
    #error "Only 32, 64, or 128 lines of height are supported!"
#endif

    main_oled_WriteCommand(0xA4);  // 0xa4,Output follows RAM content;0xa5,Output ignores RAM content

    main_oled_WriteCommand(0xD3);  //-set display offset - CHECK
    main_oled_WriteCommand(0x00);  //-not offset

    main_oled_WriteCommand(0xD5);  //--set display clock divide ratio/oscillator frequency
    main_oled_WriteCommand(0xF0);  //--set divide ratio

    main_oled_WriteCommand(0xD9);  //--set pre-charge period
    main_oled_WriteCommand(0x22);  //

    main_oled_WriteCommand(0xDA);  //--set com pins hardware configuration - CHECK
#if (MAIN_OLED_HEIGHT == 32)
    main_oled_WriteCommand(0x02);
#elif (MAIN_OLED_HEIGHT == 64)
    main_oled_WriteCommand(0x12);
#elif (MAIN_OLED_HEIGHT == 128)
    main_oled_WriteCommand(0x12);
#else
    #error "Only 32, 64, or 128 lines of height are supported!"
#endif

    main_oled_WriteCommand(0xDB);  //--set vcomh
    main_oled_WriteCommand(0x20);  // 0x20,0.77xVcc

    main_oled_WriteCommand(0x8D);  //--set DC-DC enable
    main_oled_WriteCommand(0x14);  //
    main_oled_SetDisplayOn(1);     //--turn on SSD1306 panel

    // Clear screen
    main_oled_Fill(Black);

    // Flush buffer to screen
    main_oled_UpdateScreen();

    // Set default values for screen object
    MAIN_OLED.CurrentX = 0;
    MAIN_OLED.CurrentY = 0;

    MAIN_OLED.Initialized = 1;
}

/* Fill the whole screen with the given color */
void main_oled_Fill(SSD1306_COLOR color)
{
    memset(MAIN_OLED_Buffer, (color == Black) ? 0x00 : 0xFF, sizeof(MAIN_OLED_Buffer));
}

/* Write the screenbuffer with changed to the screen */
void main_oled_UpdateScreen(void)
{
    // Write data to each page of RAM. Number of pages
    // depends on the screen height:
    //
    //  * 32px   ==  4 pages
    //  * 64px   ==  8 pages
    //  * 128px  ==  16 pages
    for (uint8_t i = 0; i < MAIN_OLED_HEIGHT / 8; i++)
    {
        main_oled_WriteCommand(0xB0 + i);  // Set the current RAM page address.
        main_oled_WriteCommand(0x00 + MAIN_OLED_X_OFFSET_LOWER);
        main_oled_WriteCommand(0x10 + MAIN_OLED_X_OFFSET_UPPER);
        main_oled_WriteData(&MAIN_OLED_Buffer[MAIN_OLED_WIDTH * i], MAIN_OLED_WIDTH);
    }
}

void main_oled_UpdateScreenPages(uint8_t start_page, uint8_t end_page)
{
    uint8_t max_page = (uint8_t) (MAIN_OLED_HEIGHT / 8U);
    if (max_page == 0U)
    {
        return;
    }

    if (start_page >= max_page)
    {
        return;
    }
    if (end_page >= max_page)
    {
        end_page = (uint8_t) (max_page - 1U);
    }
    if (start_page > end_page)
    {
        return;
    }

    for (uint8_t i = start_page; i <= end_page; i++)
    {
        main_oled_WriteCommand(0xB0 + i);  // Set the current RAM page address.
        main_oled_WriteCommand(0x00 + MAIN_OLED_X_OFFSET_LOWER);
        main_oled_WriteCommand(0x10 + MAIN_OLED_X_OFFSET_UPPER);
        main_oled_WriteData(&MAIN_OLED_Buffer[MAIN_OLED_WIDTH * i], MAIN_OLED_WIDTH);
    }
}

/*
 * Draw one pixel in the screenbuffer
 * X => X Coordinate
 * Y => Y Coordinate
 * color => Pixel color
 */
void main_oled_DrawPixel(uint8_t x, uint8_t y, SSD1306_COLOR color)
{
    if (x >= MAIN_OLED_WIDTH || y >= MAIN_OLED_HEIGHT)
    {
        // Don't write outside the buffer
        return;
    }

    // Draw in the right color
    if (color == White)
    {
        MAIN_OLED_Buffer[x + (y / 8) * MAIN_OLED_WIDTH] |= 1 << (y % 8);
    }
    else
    {
        MAIN_OLED_Buffer[x + (y / 8) * MAIN_OLED_WIDTH] &= ~(1 << (y % 8));
    }
}

/*
 * Draw 1 char to the screen buffer
 * ch       => char om weg te schrijven
 * Font     => Font waarmee we gaan schrijven
 * color    => Black or White
 */
char main_oled_WriteChar(char ch, SSD1306_Font_t Font, SSD1306_COLOR color)
{
    uint32_t i, b, j;

    // Check if character is valid
    if (ch < 32 || ch > 126)
        return 0;

    // Char width is not equal to font width for proportional font
    const uint8_t char_width = Font.char_width ? Font.char_width[ch - 32] : Font.width;
    // Check remaining space on current line
    if (MAIN_OLED_WIDTH < (MAIN_OLED.CurrentX + char_width) ||
        MAIN_OLED_HEIGHT < (MAIN_OLED.CurrentY + Font.height))
    {
        // Not enough space on current line
        return 0;
    }

    // Use the font to write
    for (i = 0; i < Font.height; i++)
    {
        b = Font.data[(ch - 32) * Font.height + i];
        for (j = 0; j < char_width; j++)
        {
            if ((b << j) & 0x8000)
            {
                main_oled_DrawPixel(MAIN_OLED.CurrentX + j, (MAIN_OLED.CurrentY + i), (SSD1306_COLOR) color);
            }
            else
            {
                main_oled_DrawPixel(MAIN_OLED.CurrentX + j, (MAIN_OLED.CurrentY + i), (SSD1306_COLOR) !color);
            }
        }
    }

    // The current space is now taken
    MAIN_OLED.CurrentX += char_width;

    // Return written char for validation
    return ch;
}

/* Write full string to screenbuffer */
char main_oled_WriteString(char* str, SSD1306_Font_t Font, SSD1306_COLOR color)
{
    while (*str)
    {
        if (main_oled_WriteChar(*str, Font, color) != *str)
        {
            // Char could not be written
            return *str;
        }
        str++;
    }

    // Everything ok
    return *str;
}

/* Position the cursor */
void main_oled_SetCursor(uint8_t x, uint8_t y)
{
    MAIN_OLED.CurrentX = x;
    MAIN_OLED.CurrentY = y;
}

/* Draw line by Bresenhem's algorithm */
void main_oled_Line(uint8_t x1, uint8_t y1, uint8_t x2, uint8_t y2, SSD1306_COLOR color)
{
    int32_t deltaX = abs(x2 - x1);
    int32_t deltaY = abs(y2 - y1);
    int32_t signX  = ((x1 < x2) ? 1 : -1);
    int32_t signY  = ((y1 < y2) ? 1 : -1);
    int32_t error  = deltaX - deltaY;
    int32_t error2;

    main_oled_DrawPixel(x2, y2, color);

    while ((x1 != x2) || (y1 != y2))
    {
        main_oled_DrawPixel(x1, y1, color);
        error2 = error * 2;
        if (error2 > -deltaY)
        {
            error -= deltaY;
            x1 += signX;
        }

        if (error2 < deltaX)
        {
            error += deltaX;
            y1 += signY;
        }
    }
    return;
}

/* Draw polyline */
void main_oled_Polyline(const MAIN_OLED_VERTEX* par_vertex, uint16_t par_size, SSD1306_COLOR color)
{
    uint16_t i;
    if (par_vertex == NULL)
    {
        return;
    }

    for (i = 1; i < par_size; i++)
    {
        main_oled_Line(par_vertex[i - 1].x, par_vertex[i - 1].y, par_vertex[i].x, par_vertex[i].y, color);
    }

    return;
}

/* Convert Degrees to Radians */
static float main_oled_DegToRad(float par_deg)
{
    return par_deg * (3.14f / 180.0f);
}

/* Normalize degree to [0;360] */
static uint16_t main_oled_NormalizeTo0_360(uint16_t par_deg)
{
    uint16_t loc_angle;
    if (par_deg <= 360)
    {
        loc_angle = par_deg;
    }
    else
    {
        loc_angle = par_deg % 360;
        loc_angle = (loc_angle ? loc_angle : 360);
    }
    return loc_angle;
}

/*
 * DrawArc. Draw angle is beginning from 4 quart of trigonometric circle (3pi/2)
 * start_angle in degree
 * sweep in degree
 */
void main_oled_DrawArc(uint8_t x, uint8_t y, uint8_t radius, uint16_t start_angle, uint16_t sweep, SSD1306_COLOR color)
{
    static const uint8_t CIRCLE_APPROXIMATION_SEGMENTS = 36;
    float approx_degree;
    uint32_t approx_segments;
    uint8_t xp1, xp2;
    uint8_t yp1, yp2;
    uint32_t count;
    uint32_t loc_sweep;
    float rad;

    loc_sweep = main_oled_NormalizeTo0_360(sweep);

    count           = (main_oled_NormalizeTo0_360(start_angle) * CIRCLE_APPROXIMATION_SEGMENTS) / 360;
    approx_segments = (loc_sweep * CIRCLE_APPROXIMATION_SEGMENTS) / 360;
    approx_degree   = loc_sweep / (float) approx_segments;
    while (count < approx_segments)
    {
        rad = main_oled_DegToRad(count * approx_degree);
        xp1 = x + (int8_t) (sinf(rad) * radius);
        yp1 = y + (int8_t) (cosf(rad) * radius);
        count++;
        if (count != approx_segments)
        {
            rad = main_oled_DegToRad(count * approx_degree);
        }
        else
        {
            rad = main_oled_DegToRad(loc_sweep);
        }
        xp2 = x + (int8_t) (sinf(rad) * radius);
        yp2 = y + (int8_t) (cosf(rad) * radius);
        main_oled_Line(xp1, yp1, xp2, yp2, color);
    }

    return;
}

/*
 * Draw arc with radius line
 * Angle is beginning from 4 quart of trigonometric circle (3pi/2)
 * start_angle: start angle in degree
 * sweep: finish angle in degree
 */
void main_oled_DrawArcWithRadiusLine(uint8_t x, uint8_t y, uint8_t radius, uint16_t start_angle, uint16_t sweep, SSD1306_COLOR color)
{
    const uint32_t CIRCLE_APPROXIMATION_SEGMENTS = 36;
    float approx_degree;
    uint32_t approx_segments;
    uint8_t xp1;
    uint8_t xp2 = 0;
    uint8_t yp1;
    uint8_t yp2 = 0;
    uint32_t count;
    uint32_t loc_sweep;
    float rad;

    loc_sweep = main_oled_NormalizeTo0_360(sweep);

    count           = (main_oled_NormalizeTo0_360(start_angle) * CIRCLE_APPROXIMATION_SEGMENTS) / 360;
    approx_segments = (loc_sweep * CIRCLE_APPROXIMATION_SEGMENTS) / 360;
    approx_degree   = loc_sweep / (float) approx_segments;

    rad                   = main_oled_DegToRad(count * approx_degree);
    uint8_t first_point_x = x + (int8_t) (sinf(rad) * radius);
    uint8_t first_point_y = y + (int8_t) (cosf(rad) * radius);
    while (count < approx_segments)
    {
        rad = main_oled_DegToRad(count * approx_degree);
        xp1 = x + (int8_t) (sinf(rad) * radius);
        yp1 = y + (int8_t) (cosf(rad) * radius);
        count++;
        if (count != approx_segments)
        {
            rad = main_oled_DegToRad(count * approx_degree);
        }
        else
        {
            rad = main_oled_DegToRad(loc_sweep);
        }
        xp2 = x + (int8_t) (sinf(rad) * radius);
        yp2 = y + (int8_t) (cosf(rad) * radius);
        main_oled_Line(xp1, yp1, xp2, yp2, color);
    }

    // Radius line
    main_oled_Line(x, y, first_point_x, first_point_y, color);
    main_oled_Line(x, y, xp2, yp2, color);
    return;
}

/* Draw circle by Bresenhem's algorithm */
void main_oled_DrawCircle(uint8_t par_x, uint8_t par_y, uint8_t par_r, SSD1306_COLOR par_color)
{
    int32_t x   = -par_r;
    int32_t y   = 0;
    int32_t err = 2 - 2 * par_r;
    int32_t e2;

    if (par_x >= MAIN_OLED_WIDTH || par_y >= MAIN_OLED_HEIGHT)
    {
        return;
    }

    do
    {
        main_oled_DrawPixel(par_x - x, par_y + y, par_color);
        main_oled_DrawPixel(par_x + x, par_y + y, par_color);
        main_oled_DrawPixel(par_x + x, par_y - y, par_color);
        main_oled_DrawPixel(par_x - x, par_y - y, par_color);
        e2 = err;

        if (e2 <= y)
        {
            y++;
            err = err + (y * 2 + 1);
            if (-x == y && e2 <= x)
            {
                e2 = 0;
            }
        }

        if (e2 > x)
        {
            x++;
            err = err + (x * 2 + 1);
        }
    } while (x <= 0);

    return;
}

/* Draw filled circle. Pixel positions calculated using Bresenham's algorithm */
void main_oled_FillCircle(uint8_t par_x, uint8_t par_y, uint8_t par_r, SSD1306_COLOR par_color)
{
    int32_t x   = -par_r;
    int32_t y   = 0;
    int32_t err = 2 - 2 * par_r;
    int32_t e2;

    if (par_x >= MAIN_OLED_WIDTH || par_y >= MAIN_OLED_HEIGHT)
    {
        return;
    }

    do
    {
        for (uint8_t _y = (par_y + y); _y >= (par_y - y); _y--)
        {
            for (uint8_t _x = (par_x - x); _x >= (par_x + x); _x--)
            {
                main_oled_DrawPixel(_x, _y, par_color);
            }
        }

        e2 = err;
        if (e2 <= y)
        {
            y++;
            err = err + (y * 2 + 1);
            if (-x == y && e2 <= x)
            {
                e2 = 0;
            }
        }

        if (e2 > x)
        {
            x++;
            err = err + (x * 2 + 1);
        }
    } while (x <= 0);

    return;
}

/* Draw a rectangle */
void main_oled_DrawRectangle(uint8_t x1, uint8_t y1, uint8_t x2, uint8_t y2, SSD1306_COLOR color)
{
    main_oled_Line(x1, y1, x2, y1, color);
    main_oled_Line(x2, y1, x2, y2, color);
    main_oled_Line(x2, y2, x1, y2, color);
    main_oled_Line(x1, y2, x1, y1, color);

    return;
}

/* Draw a filled rectangle */
void main_oled_FillRectangle(uint8_t x1, uint8_t y1, uint8_t x2, uint8_t y2, SSD1306_COLOR color)
{
    uint8_t x_start = ((x1 <= x2) ? x1 : x2);
    uint8_t x_end   = ((x1 <= x2) ? x2 : x1);
    uint8_t y_start = ((y1 <= y2) ? y1 : y2);
    uint8_t y_end   = ((y1 <= y2) ? y2 : y1);

    for (uint8_t y = y_start; (y <= y_end) && (y < MAIN_OLED_HEIGHT); y++)
    {
        for (uint8_t x = x_start; (x <= x_end) && (x < MAIN_OLED_WIDTH); x++)
        {
            main_oled_DrawPixel(x, y, color);
        }
    }
    return;
}

SSD1306_Error_t main_oled_InvertRectangle(uint8_t x1, uint8_t y1, uint8_t x2, uint8_t y2)
{
    if ((x2 >= MAIN_OLED_WIDTH) || (y2 >= MAIN_OLED_HEIGHT))
    {
        return SSD1306_ERR;
    }
    if ((x1 > x2) || (y1 > y2))
    {
        return SSD1306_ERR;
    }
    uint32_t i;
    if ((y1 / 8) != (y2 / 8))
    {
        /* if rectangle doesn't lie on one 8px row */
        for (uint32_t x = x1; x <= x2; x++)
        {
            i = x + (y1 / 8) * MAIN_OLED_WIDTH;
            MAIN_OLED_Buffer[i] ^= 0xFF << (y1 % 8);
            i += MAIN_OLED_WIDTH;
            for (; i < x + (y2 / 8) * MAIN_OLED_WIDTH; i += MAIN_OLED_WIDTH)
            {
                MAIN_OLED_Buffer[i] ^= 0xFF;
            }
            MAIN_OLED_Buffer[i] ^= 0xFF >> (7 - (y2 % 8));
        }
    }
    else
    {
        /* if rectangle lies on one 8px row */
        const uint8_t mask = (0xFF << (y1 % 8)) & (0xFF >> (7 - (y2 % 8)));
        for (i = x1 + (y1 / 8) * MAIN_OLED_WIDTH;
             i <= (uint32_t) x2 + (y2 / 8) * MAIN_OLED_WIDTH; i++)
        {
            MAIN_OLED_Buffer[i] ^= mask;
        }
    }
    return SSD1306_OK;
}

/* Draw a bitmap */
void main_oled_DrawBitmap(uint8_t x, uint8_t y, const unsigned char* bitmap, uint8_t w, uint8_t h, SSD1306_COLOR color)
{
    int16_t byteWidth = (w + 7) / 8;  // Bitmap scanline pad = whole byte
    uint8_t byte      = 0;

    if (x >= MAIN_OLED_WIDTH || y >= MAIN_OLED_HEIGHT)
    {
        return;
    }

    for (uint8_t j = 0; j < h; j++, y++)
    {
        for (uint8_t i = 0; i < w; i++)
        {
            if (i & 7)
            {
                byte <<= 1;
            }
            else
            {
                byte = (*(const unsigned char*) (&bitmap[j * byteWidth + i / 8]));
            }

            if (byte & 0x80)
            {
                main_oled_DrawPixel(x + i, y, color);
            }
        }
    }
    return;
}

void main_oled_SetContrast(const uint8_t value)
{
    const uint8_t kSetContrastControlRegister = 0x81;
    main_oled_WriteCommand(kSetContrastControlRegister);
    main_oled_WriteCommand(value);
}

void main_oled_SetDisplayOn(const uint8_t on)
{
    uint8_t value;
    if (on)
    {
        value               = 0xAF;  // Display on
        MAIN_OLED.DisplayOn = 1;
    }
    else
    {
        value               = 0xAE;  // Display off
        MAIN_OLED.DisplayOn = 0;
    }
    main_oled_WriteCommand(value);
}

uint8_t main_oled_GetDisplayOn()
{
    return MAIN_OLED.DisplayOn;
}

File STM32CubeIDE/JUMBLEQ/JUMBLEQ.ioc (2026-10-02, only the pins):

Mcu.UserName=STM32H7S3Z8Tx
PA0.Signal=ADCx_INP0
PA10.Signal=S_TIM1_CH3
PA13(JTMS/SWDIO).Signal=DEBUG_JTMS-SWDIO
PA14(JTCK/SWCLK).Signal=DEBUG_JTCK-SWCLK
PA3.Signal=ADCx_INP15
PA4.Signal=ADC1_INP18
PA5.Signal=ADC2_INP18
PA6.Signal=ADCx_INP3
PA8.Signal=I2C3_SCL
PA9.Signal=I2C3_SDA
PB1.Signal=ADCx_INP5
PB10.Signal=I2C2_SCL
PB11.Signal=I2C2_SDA
PB12.GPIO_Label=S3
PB12.Signal=GPIO_Output
PB13.GPIO_Label=CODEC_RESET
PB13.Signal=GPIO_Output
PC0.Signal=ADCx_INP10
PC2.Signal=ADCx_INP12
PC3.Signal=ADCx_INP13
PC9.Signal=I2S_CKIN
PD0.GPIO_Label=LED2
PD0.Signal=GPIO_Output
PD1.GPIO_Label=LED1
PD1.Signal=GPIO_Output
PD10.GPIO_Label=S2
PD10.Signal=GPIO_Output
PD11.Signal=SAI2_SD_A
PD12.Signal=SAI2_FS_A
PD13.Signal=SAI2_SCK_A
PD14.GPIO_Label=SW2
PD14.Signal=GPIO_Input
PD15.GPIO_Label=SW1
PD15.Signal=GPIO_Input
PD2.GPIO_Label=LED0
PD2.Signal=GPIO_Output
PD8.GPIO_Label=S0
PD8.Signal=GPIO_Output
PD9.GPIO_Label=S1
PD9.Signal=GPIO_Output
PE4.Signal=SAI1_FS_A
PE5.Signal=SAI1_SCK_A
PE6.Signal=SAI1_SD_A
PH0-OSC_IN(PH0).Signal=RCC_OSC_IN
PH1-OSC_OUT(PH1).GPIO_Label=DSP_RESET
PH1-OSC_OUT(PH1).Signal=GPIO_Output

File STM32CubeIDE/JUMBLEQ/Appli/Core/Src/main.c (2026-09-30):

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
/* Includes ------------------------------------------------------------------*/
#include "main.h"
#include "FreeRTOS.h"
#include "cmsis_os2.h"
#include "adc.h"
#include "gpdma.h"
#include "hpdma.h"
#include "i2c.h"
#include "sai.h"
#include "spi.h"
#include "tim.h"
#include "usb_otg.h"
#include "gpio.h"

/* USER CODE BEGIN Includes */
#include "audio_control.h"
#include "eeprom.h"
#include "led_control.h"
/* USER CODE END Includes */


void MX_FREERTOS_Init(void);
/* USER CODE BEGIN PFP */
static void MPU_Config(void);
/* USER CODE END PFP */

/* USER CODE BEGIN 0 */
int __io_putchar(uint8_t ch)
{
    return ITM_SendChar(ch);
}

static void dwt_init(void)
{
    /* Enable DWT cycle counter for timing measurements */
    CoreDebug->DEMCR |= CoreDebug_DEMCR_TRCENA_Msk;
    DWT->CYCCNT = 0;
    DWT->CTRL |= DWT_CTRL_CYCCNTENA_Msk;
}

void HAL_GPIO_EXTI_Callback(uint16_t GPIO_Pin)
{
    if (GPIO_Pin == UCPD_FLG_n_Pin)
    {
        HAL_GPIO_WritePin(UCPD_PWR_EN_GPIO_Port, UCPD_PWR_EN_Pin, GPIO_PIN_RESET);
    }
}

/* USER CODE END 0 */

/**
  * @brief  The application entry point.
  * @retval int
  */
int main(void)
{

  /* USER CODE BEGIN 1 */
    /* MPU Configuration--------------------------------------------------------*/
    MPU_Config();
  /* USER CODE END 1 */

  /* Enable the CPU Cache */

  /* Enable I-Cache---------------------------------------------------------*/
  SCB_EnableICache();

  /* Enable D-Cache---------------------------------------------------------*/
  SCB_EnableDCache();

  /* MCU Configuration--------------------------------------------------------*/

  /* Update SystemCoreClock variable according to RCC registers values. */
  SystemCoreClockUpdate();

  /* Reset of all peripherals, Initializes the Flash interface and the Systick. */
  HAL_Init();

  /* USER CODE BEGIN SysInit */
    dwt_init();

  /* USER CODE END SysInit */

  /* Initialize all configured peripherals */
  MX_GPIO_Init();
  MX_GPDMA1_Init();
  MX_HPDMA1_Init();
  MX_USB_OTG_HS_PCD_Init();
  MX_I2C3_Init();
  MX_SPI5_Init();
  MX_SAI1_Init();
  MX_TIM1_Init();
  MX_SAI2_Init();
  MX_ADC1_Init();
  MX_I2C2_Init();
  MX_ADC2_Init();
  /* USER CODE BEGIN 2 */
    if (EEPROM_CheckConnection(&hi2c2) == HAL_OK)
    {
        SEGGER_RTT_printf(0, "EEPROM CAT24C512 detected on I2C2 (0x50)\r\n");
    }
    else
    {
        SEGGER_RTT_printf(0, "EEPROM CAT24C512 not detected on I2C2 (0x50)\r\n");
        Error_Handler();
    }

  /* USER CODE END 2 */

  /* Init scheduler */
  osKernelInitialize();  /* Call init function for freertos objects (in cmsis_os2.c) */
  MX_FREERTOS_Init();

  /* Start scheduler */
  osKernelStart();

  /* We should never get here as control is now taken by the scheduler */

  /* Infinite loop */
  /* USER CODE BEGIN WHILE */
    while (1)
    {
    /* USER CODE END WHILE */

    /* USER CODE BEGIN 3 */
        // FreeRTOS使用時はここに到達しない
        // すべての処理はタスク（freertos.c）で実行される
    }
  /* USER CODE END 3 */
}

/* USER CODE BEGIN 4 */
/* MPU Configuration */
static void MPU_Config(void)
{
    MPU_Region_InitTypeDef MPU_InitStruct = {0};

    /* Disable the MPU */
    HAL_MPU_Disable();

    /* Region 0: default no access for undefined regions */
    MPU_InitStruct.Enable           = MPU_REGION_ENABLE;
    MPU_InitStruct.Number           = MPU_REGION_NUMBER0;
    MPU_InitStruct.BaseAddress      = 0x00000000;
    MPU_InitStruct.Size             = MPU_REGION_SIZE_4GB;
    MPU_InitStruct.SubRegionDisable = 0x87;
    MPU_InitStruct.TypeExtField     = MPU_TEX_LEVEL0;
    MPU_InitStruct.AccessPermission = MPU_REGION_NO_ACCESS;
    MPU_InitStruct.DisableExec      = MPU_INSTRUCTION_ACCESS_DISABLE;
    MPU_InitStruct.IsShareable      = MPU_ACCESS_NOT_SHAREABLE;
    MPU_InitStruct.IsCacheable      = MPU_ACCESS_NOT_CACHEABLE;
    MPU_InitStruct.IsBufferable     = MPU_ACCESS_NOT_BUFFERABLE;
    HAL_MPU_ConfigRegion(&MPU_InitStruct);

    /* Region 1: external XSPI flash (XIP) */
    MPU_InitStruct.Enable           = MPU_REGION_ENABLE;
    MPU_InitStruct.Number           = MPU_REGION_NUMBER1;
    MPU_InitStruct.BaseAddress      = 0x90000000;
    MPU_InitStruct.Size             = MPU_REGION_SIZE_32MB;
    MPU_InitStruct.SubRegionDisable = 0x00;
    MPU_InitStruct.AccessPermission = MPU_REGION_FULL_ACCESS;
    MPU_InitStruct.DisableExec      = MPU_INSTRUCTION_ACCESS_ENABLE;
    MPU_InitStruct.IsCacheable      = MPU_ACCESS_CACHEABLE;
    MPU_InitStruct.IsBufferable     = MPU_ACCESS_BUFFERABLE;
    HAL_MPU_ConfigRegion(&MPU_InitStruct);

    /* Region 2: AXI SRAM */
    MPU_InitStruct.Number      = MPU_REGION_NUMBER2;
    MPU_InitStruct.BaseAddress = 0x24000000;
    MPU_InitStruct.Size        = MPU_REGION_SIZE_256KB;
    MPU_InitStruct.DisableExec = MPU_INSTRUCTION_ACCESS_DISABLE;
    HAL_MPU_ConfigRegion(&MPU_InitStruct);

    /* Region 3: noncacheable buffer */
    MPU_InitStruct.Number       = MPU_REGION_NUMBER3;
    MPU_InitStruct.BaseAddress  = 0x24040000;
    MPU_InitStruct.Size         = MPU_REGION_SIZE_256KB;
    MPU_InitStruct.TypeExtField = MPU_TEX_LEVEL1;
    MPU_InitStruct.IsCacheable  = MPU_ACCESS_NOT_CACHEABLE;
    MPU_InitStruct.IsBufferable = MPU_ACCESS_NOT_BUFFERABLE;
    HAL_MPU_ConfigRegion(&MPU_InitStruct);

    /* Region 4: block speculative access to unused GFXMMU memory.
     * ES0596 2.2.17 also applies to devices without GFXMMU. Use
     * Strongly-ordered, no-access and XN attributes for the entire range.
     */
    MPU_InitStruct.Enable           = MPU_REGION_ENABLE;
    MPU_InitStruct.Number           = MPU_REGION_NUMBER4;
    MPU_InitStruct.BaseAddress      = 0x25000000;
    MPU_InitStruct.Size             = MPU_REGION_SIZE_16MB;
    MPU_InitStruct.SubRegionDisable = 0x00;
    MPU_InitStruct.TypeExtField     = MPU_TEX_LEVEL0;
    MPU_InitStruct.AccessPermission = MPU_REGION_NO_ACCESS;
    MPU_InitStruct.DisableExec      = MPU_INSTRUCTION_ACCESS_DISABLE;
    MPU_InitStruct.IsShareable      = MPU_ACCESS_SHAREABLE;
    MPU_InitStruct.IsCacheable      = MPU_ACCESS_NOT_CACHEABLE;
    MPU_InitStruct.IsBufferable     = MPU_ACCESS_NOT_BUFFERABLE;
    HAL_MPU_ConfigRegion(&MPU_InitStruct);

    /* Enable the MPU */
    HAL_MPU_Enable(MPU_PRIVILEGED_DEFAULT);
}
/* USER CODE END 4 */

/**
  * @brief  Period elapsed callback in non blocking mode
  * @note   This function is called  when TIM6 interrupt took place, inside
  * HAL_TIM_IRQHandler(). It makes a direct call to HAL_IncTick() to increment
  * a global variable "uwTick" used as application time base.
  * @param  htim TIM handle
  * @retval None
  */
void HAL_TIM_PeriodElapsedCallback(TIM_HandleTypeDef* htim)
{
    if (htim->Instance == TIM6)
    {
    HAL_IncTick();
  }
}
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

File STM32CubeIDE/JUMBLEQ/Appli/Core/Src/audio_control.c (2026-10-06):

/*
 * audio_control.c
 *
 * Audio subsystem facade and Audio Task arbitration.
 *
 * Owns the applied sample-rate state and the top-level Audio Task that applies
 * USB requests. The UAC2 control plane lives in audio_usb_control.c, realtime
 * data movement in audio_transport.c, EEPROM settings in eeprom_config.c.
 */

#include "audio_control.h"
#include "audio_control_internal.h"
#include "audio_diagnostics_internal.h"
#include "audio_transport_internal.h"
#include "audio_usb_control_internal.h"
#include "eeprom_config_internal.h"
#include "ui_control_internal.h"
#include "ui_adc_control_internal.h"
#include "ui_routing_control_internal.h"
#include "timecode_synth.h"

#include "adc.h"
#include "hpdma.h"
#include "i2c.h"
#include "linked_list.h"
#include "eeprom.h"

#include "adau1466.h"
#include "SEGGER_RTT.h"

#include "cmsis_os2.h"

enum
{
    AUDIO_TASK_STATS_PERIOD_MS = 1000u,
    // DMA復旧: TX開始からRX開始までの同期待ち（既存レート変更と同じ10ms）
    AUDIO_RECOVERY_TX_SYNC_DELAY_MS = 10u,
    // 連続失敗時の再試行間隔
    AUDIO_RECOVERY_BACKOFF_MS = 100u,
    // この回数だけ連続失敗したらFAILEDへラッチし、両経路停止・無音を維持する
    AUDIO_RECOVERY_MAX_CONSECUTIVE_FAILURES = 3u,
    // commit区間mutexの取得待ち上限。commit自体は短く、通常は即時取得できる
    AUDIO_COMMIT_LOCK_TIMEOUT_MS = 20u,
};

extern DMA_QListTypeDef List_HPDMA1_Channel0;

// DMA/SAIエラーからの復旧状態。ISR共有状態とは分離し、状態遷移はAudio Taskだけが行う。
typedef enum
{
    AUDIO_RECOVERY_STATE_IDLE = 0,
    AUDIO_RECOVERY_STATE_PREPARE,
    AUDIO_RECOVERY_STATE_WAIT_TX_SYNC,
    AUDIO_RECOVERY_STATE_BACKOFF,
    AUDIO_RECOVERY_STATE_FAILED,
} audio_control_recovery_state_t;

static audio_control_recovery_state_t s_recovery_state = AUDIO_RECOVERY_STATE_IDLE;
static uint32_t s_recovery_request_sequence = 0u;
static bool s_recovery_request_in_flight = false;
static uint32_t s_recovery_wait_start_tick = 0u;
static uint32_t s_recovery_backoff_start_tick = 0u;
static uint32_t s_recovery_consecutive_failures = 0u;

// サンプルレートの要求状態(USB Taskが更新)と適用状態(Audio Taskが更新)。
// 要求はレートとsequenceを一組でpublishし、Audio Taskは同じcritical sectionで
// 両方をsnapshotして処理対象を固定する。適用済みレートは「最後に切り替え全体が
// 成功した値」、有効フラグは「現在もその設定を信用できるか」を表す。
typedef struct
{
    volatile uint32_t requested_hz;        // 最後に受理した要求値。適用完了前でも更新される
    volatile uint32_t requested_sequence;  // 受理ごとに増加する要求sequence
    volatile bool change_pending;          // Audio Taskが処理すべき変更要求がある
    uint32_t applied_hz;                   // 最後に切り替え全体が成功した値
    uint32_t applied_sequence;             // 適用が確定した要求sequence
    bool applied_hz_valid;                 // 現在もその設定を信用できるか
    volatile uint32_t state;               // audio_control_rate_state_t
} audio_control_sample_rate_state_t;

static audio_control_sample_rate_state_t s_sample_rate = {
    .requested_hz       = 48000U,
    .requested_sequence = 0U,
    .change_pending     = false,
    .applied_hz         = 48000U,
    .applied_sequence   = 0U,
    .applied_hz_valid   = false,  // 初期適用確認まで無効
    .state              = AUDIO_RATE_STATE_SWITCHING,
};

// ISR/USB callbackから参照する物理搬送レートと搬送許可。READY時は適用値、
// 切り替え中は固定targetを保持する（複合状態をatomicに読める単純値として公開）。
static volatile uint32_t s_transport_rate_hz = 48000U;
static volatile bool s_transport_rate_ready = false;
// 要求受理から処理開始までの未処理期間gate。受理直後から通常搬送を禁止し、
// Audio Taskが処理対象を固定した時点で解除する。
static volatile bool s_rate_change_unprocessed = false;
// DMA/SAIが停止確認を経て安全な状態にあるか。停止未確認のまま復旧がBACKOFF/FAILEDへ
// 入った場合、DMA参照バッファを通常搬送で再利用しないためのgate。
static volatile bool s_transport_paths_safe = true;

// 搬送のcommit区間とレート要求publishを直列化するmutex。時間のかかるTinyUSB APIを
// 割り込み禁止区間へ入れずに排他する。Audio Task起動時に生成する。
static osMutexId_t s_commit_mutex = NULL;
static const osMutexAttr_t s_commit_mutex_attributes = {
    .name = "audioCommit",
};

static void audio_rate_switch_process(uint32_t target_hz, uint32_t target_sequence);
static void audio_recovery_process(void);
static void audio_recovery_release_latch(void);
static void audio_recovery_reset_after_rate_change(void);
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

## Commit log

2026-01-30 RHPORT1がUSB HSなのに0を定義してたので修正
2026-01-30 フォーマット修正
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2026-02-06 非キャッシュ領域の範囲を修正
2026-02-07 入力chをどちらもLINE入力にする
    [oto_no_ita_dsp_ADAU146xSchematic_1.param]
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2026-02-07 実際のフラッシュサイズに合わせて修正
2026-02-07 範囲修正
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2026-02-10 Errata 2.2.15への対処コードを追加
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2026-02-12 外形寸法を記入
    [OTO_NO_ITA.kicad_pcb]
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2026-02-12 サンプルレート切り替え時のAK4619再初期化時のI2C排他漏れを修正
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2026-02-13 Update README to reflect changes in prototype and pinout
    Removed images related to Prototype 1 and Main board, added Pinout section with image.
2026-02-13 Add image gallery for prototypes and main board
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2026-02-13 電源投入時にOLEDが描画されない不具合を修正
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2026-02-13 部品値を修正
    [OTO_NO_TE.kicad_sch]
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2026-02-17 サブOLEDの描画用関数名を修正
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2026-02-17 XF assignの初期値修正
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2026-02-18 THRU列のクリア処理を修正
2026-02-18 入力タイプを切り替えたときに正しく描画されるよう修正
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2026-02-18 Gain（Ch.1、Ch.2、Mst）とDry/Wetの表示レンジを修正
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2026-02-18 double値を8.24形式の固定小数点に変換する関数を修正
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2026-02-18 SigmaStudio+のプロジェクト名を修正
    [JUMBLEQ_DSP_ADAU146xSchematic_1.param, oto_no_ita_dsp_ADAU146xSchematic_1.param]
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2026-02-20 オーバーフローの回避処理がフレーム境界に揃っていない不具合を修正
2026-02-20 ホスト側でオーディオ入力名が「JUMBLEQ Stereo IN」となるように修正
    USB Audio Functionを2つに分離（OUT専用とIN専用）
    [audio_control.c, tusb_config.h]
2026-02-20 POT数を8から12に、磁気スイッチを6から10に変更
    [BOM-OTO_NO_TE.csv, OTO_NO_TE.kicad_pcb, OTO_NO_TE.kicad_sch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]
2026-02-20 djayのDVSに対応するためのルーティングを追加
    [JUMBLEQ_DSP_ADAU146xSchematic_1.param]
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2026-02-22 THRU設定でもUSB[3/4]を選択出来るようにする
    [JUMBLEQ_DSP_ADAU146xSchematic_1.param]
2026-02-22 ホストに表示される入出力名を修正
2026-02-25 XF assignでUSB[3/4]を切り替えられるようにumenu修正
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2026-02-25 【Boot】ビルド時のエラーと警告を出ないように修正
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2026-02-25 【ExtMemLoader】生成した.stldrが正しく動作するように修正
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2026-02-26 サブOLEDの初期表示のチラつきを修正
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2026-09-15 USB Master Volume/Mute制御をDSPへ反映
    [JUMBLEQ_DSP_ADAU146xSchematic_1.param]
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2026-09-15 TXリングのdrift-down判定基準を修正
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2026-09-16 USBオーディオのバッファリング処理を改善
    - USB IN/OUTのFIFO目標をサンプルレートから算出
    - FIFO容量と最大パケットに対する安全性を検証
    - ストリーム再設定を追跡する診断ログを追加
    - 診断ログを既定で無効化
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2026-09-16 オーディオDMAの取りこぼし診断と自動復旧を実装
    - TX/RXのDMAイベントdrop・サービス期限超過・RXリング破棄を永続診断へ記録
    - DMA/SAIエラーを復旧要求としてpublishし、Audio Taskで停止・再構築・再始動
    - SAIエラー割り込みはISR内でフラグ整理と復旧要求のみを行い、停止待ちを排除
    - 復旧時はSAIのMSP資源と設定を維持し、生成MspInitを再実行しない
    - レート変更と復旧を直列化し、後発エラー要求を失わない
2026-09-16 USB再生の開始待ちとドリフト補正を改善する
    - 初回primingでUSB実データ224 wordが揃うまで再生を保留し、prefill無音を再生対象に残さない
    - ドリフト補正に開始／解除閾値のヒステリシス、継続時間、最小間隔を追加
    - 補正halfは1 frameの位相移動を8 frameのクロスフェードで補間する
    - priming・閾値逸脱・補正抑制を区別する永続診断とレイテンシー説明の訂正
    - アプリバージョンをv0.15.2へ更新
2026-09-16 DSP向けSPI通信の結果判定と停止確認を改善する
    - 転送結果を表すresult型APIと永続診断g_sigma_spi_diagnosticsを新設し、
    既存のSigmaStudio互換void APIは結果を破棄するラッパーとして維持
    - IT転送は完了／エラーのcallbacksと相互排他な状態機械で確定し、期限切れ時は
    原子的最終確認で完了・エラーを取りこぼさない
    - 停止はabort戻り値に加えSPE/CSTARTとIER（DXP含む）のクリアを確認し、
    失敗時はSPI5割り込みを無効化してFAULTとしてラッチする
    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
2026-09-17 サンプルレート切替の状態整合と安全停止を実装する
    - 要求レートとsequenceを一括publishし、Audio Taskは同一critical sectionで
    targetを固定。状態をREADY/SWITCHING/FAILEDで管理し、CLK_VALIDは最新要求と
    適用状態が整合した場合だけ1にする
    - 切替はADC/HPDMA停止、SAI/GPDMA停止確認、DSP更新、再構築・TX開始、10ms待ち、
    RX開始、ADC再開の全手順成功時だけcommitし、失敗時はFAILEDで搬送を禁止する
    - DMA停止確認はHAL statusとハンドル状態で判定し、停止未確認時は参照バッファを
    消去・再利用しない。復旧の経路安全gateで通常搬送を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
    [adau1466.c, audio_control.c, audio_diagnostics.c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]
2026-09-17 USB音量・ミュート操作を非同期化する
    - Feature Unit SET_CURは要求値の更新とチャンネル別dirty bit設定のみを行い、
    USB callbackからSPI呼出し・mutex/セマフォ待ちを排除
    - 専用Task usbFeatureTask（osPriorityNormal、10ms周期）を追加し、dirty
    チャンネルを最新値へ集約してDSPへ適用。スタックとTCBは静的確保とし、
    ヒープ枯渇時のfatal hookを回避
    - ミュート要求はMute書込みを先行しGain失敗でも見送らない。ミュート解除は
    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
2026-09-18 USB音量要求の範囲と刻みを検証する (#228)
    - VOLUME_CTRL_RESOLUTION_DBを追加し、GET_RANGEのbRes・ログ・実効dB変換の
    256を定数化（値は不変）。境界と刻みの整合を_Static_assertで保証
    - SET_CUR(volume)は保存前に範囲(-50..0dB)と1dB刻みを検証し、範囲外・端数は
    STALLで拒否して保存値・dirty bit・適用要求を変更しない
    - 拒否件数・最後の拒否チャンネル/値を永続診断へ追加
    - 既存の非同期適用経路、Mute動作、master+ch合算、広告値は変更なし
    [audio_usb_control.c]
2026-09-19 コピー・補間・合成を含むDMA処理完了時間を計測する
    - TX/RXのDMA half更新で「処理開始→完了」と「callback→完了」をDWT->CYCCNTで
    計測し、half/cpltごとの最大値と完了期限超過数を永続診断へ追加
    - 完了期限はDMA half期間（half 32 frame/実サンプルレート）とし、complete最大値の
    更新時はそのイベントのdeadlineも同時保存。RX最大値はレート変更後も期限と対応
    - 世代確認済みのイベントはstream停止中も計測し、synth処理を含むsafe handoff境界を
    評価可能にする。既存service診断の意味・計測点は変更しない
    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
2026-09-19 実装と名前が食い違う公開APIを明確化する (#233)
    - get_current_sample_rate_hz() を audio_control_requested_sample_rate_hz() へ改名
    - reset_audio_buffer() を audio_control_reset_runtime_state() へ改名
    - AUDIO_LoadAndApplyRoutingFromEEPROM() を
    audio_control_load_config_or_restore_defaults() へ改名
    - start_audio_control() を ui_control_enable_runtime_processing() へ改名
    - 内部識別子（is_start_audio_control / is_started_audio_control）と呼び出し
    コメントを新名へ統一。処理・呼び出し順・副作用に変更なし
    Refs #233
    [audio_control.c, audio_usb_control.c, ui_control.c]
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2026-09-29 MIDI・ルーティング・DSPソースの値ドメインを名前で分離する
    - MIDI PC値をUI_MIDI_PROGRAM_*、UIルーティングsourceを
    UI_ROUTING_SOURCE_*、DSP入力sourceをAUDIO_INPUT_SOURCE_*、
    HP出力sourceをHP_SOURCE_*へ分離（値は変更なし）
    - MIDIコマンド表の引数をドメイン別unionへ変更し、handlerを型付き化
    - Return source適用をUI_ROUTING_SOURCE_*へ統一し、None sentinel混在を除去
    - Debug/Releaseビルドへ-Wenum-conversionを追加
    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
2026-09-29 Fader contextのrouting sourceを型付きのまま保持する
    - refresh_ch_fader_dsp_context()のローカル変数をUI_RoutingSource_tへ変更
    - enum→byte→enumの変換を除去し、-Wenum-conversionの診断を維持
    Refs #236
2026-09-30 自作公開APIのモジュール接頭辞を統一する
    - ADAU1466/AK4619/LED/UI/OLEDの公開APIを<module>_<verb>_<object>へ統一
    - UI内部の誤接頭辞・無接頭辞APIを所有モジュール接頭辞へ変更
    - ADCコールバック宣言をui_adc_control_internal.hへ移動しHAL DMA型依存を追加
    - ホストテストのモック名を新名へ更新
    Refs #235
2026-09-30 自作型とprivate識別子の命名スタイルを統一する
    - 自作型60件を<component>_<name>_tのlower_snakeへ統一
    - file-scope staticをs_+lower_snakeへ統一し、task頻度変数へ単位を付与
    - ファイル内で完結する非staticオブジェクトをstatic+s_化
    - private関数のcamel要素と略語を統一
    - dbg_*と.noinitのFault記録変数は診断例外として変更しない
    - 命名規則をDocs/reference/naming-conventions.mdへ明文化
    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
2026-10-01 USB IN録音のストリーム境界とFIFO滞留量を管理する
    - IN停止中はRXリングへ蓄積せず、timecode入力処理だけを継続
    - IN開始要求の世代を追加し、集約されたstop→startや再SET_INTERFACEでも開始境界でRXリングとIN FIFOを破棄
    - IN FIFOへの書込みに上限(4 interval)を設け、超過時は上書きさせずに保留
    - 保留分がRXリング保持上限(DMA half＋2 interval)を超えた場合はframe境界で明示的に破棄
    - FIFOの最終判定とwriteをvTaskSuspendAll区間で行い、usbTaskのFIFO clearとの競合と未適用要求時の旧世代データ書込みを防止
    - 書込み戻り値の異常(0/部分書込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
2026-10-02 SAI DMA周期をサンプルレートに依らず一定時間にする
    DMA half長をDMA構築時のサンプルレートから約0.333msに決め、48kHzでは
    16 frame、96kHzでは32 frameで動作させる。48kHzの再生・録音でDMA段の
    遅延とTXリングのpriming水位を下げる。
    - DMAノードのDataSizeを実行時の転送長マクロ（SAI_xX_DMA_XFER_BYTES）へ
    変更し、JUMBLEQ.iocとlinked_list.cの設定を一致させる
    - バッファは最大長（256 word）で確保したまま、起動時とレート変更・復旧の
    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
2026-10-02 USB IN録音のRXリングを廃止し、DMA half単位でUSB IN FIFOへ直接書き込む
    - SAI RX DMA halfをchの無音化をしながら組み立て、その場でIN FIFOへ書き込む
    - FIFO上限超過時はPRIMASK区間でFIFO先頭の古いデータを目標水位まで破棄する
    - RXリング、保持上限による破棄、tx_done ISRからのTask通知を削除する
    - USB IN診断をRXリング破棄・保留からtrim・チャンク破棄の計数へ置き換える
    Refs #259
2026-10-02 USB OUT再生のTXリングを廃止し、USB OUT FIFOからDMA halfへ直接読み出す
    - TX DMA halfごとにUSB OUT FIFOから直接読み出し、priming・underrun・ドリフト補正をFIFO水位で判定する
    - FIFOの読出し・peek・discard・overflow復旧をPRIMASK区間で行い、USB ISRとusbTaskのclearと排他する
    - 満杯・overflow時はFIFOをclearして再primingし、FIFOが空になった場合も再primingする
    - ドリフト補正を最終手段とし、保証範囲±500ppmに合わせて補正間隔を10msにする
    - USB OUT FIFOを16 packet分に拡大し、TXリングとrx_doneからのTask起床を削除する
    - OUT FIFO診断と、停止時にDMA処理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

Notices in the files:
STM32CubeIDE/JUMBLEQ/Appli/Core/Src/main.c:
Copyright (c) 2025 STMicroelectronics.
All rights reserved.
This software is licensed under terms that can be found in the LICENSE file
